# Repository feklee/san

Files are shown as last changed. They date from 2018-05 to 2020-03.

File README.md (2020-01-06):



Introduction
============

*Knowing yourself is the beginning of all wisdom* ― Aristotle

SAN (Self Aware Network) is an experiment about the [future of
architecture][1]. The network understands its own topology, a first
step towards being able to dynamically adapt to its environment.

SAN is an intermediate step: [Manifesto][6]

Getting started
===============

 1. Build nodes, edges, and the root node.

 2. Program the root node and the nodes.

 3. If using the USB root node, connect that to your computer, then run the web
    app.
    
    If using the WiFi root node, simply connect to it with a web browser.
    
 4. Build a structure.

There may be [apps][5] built on top of the system.

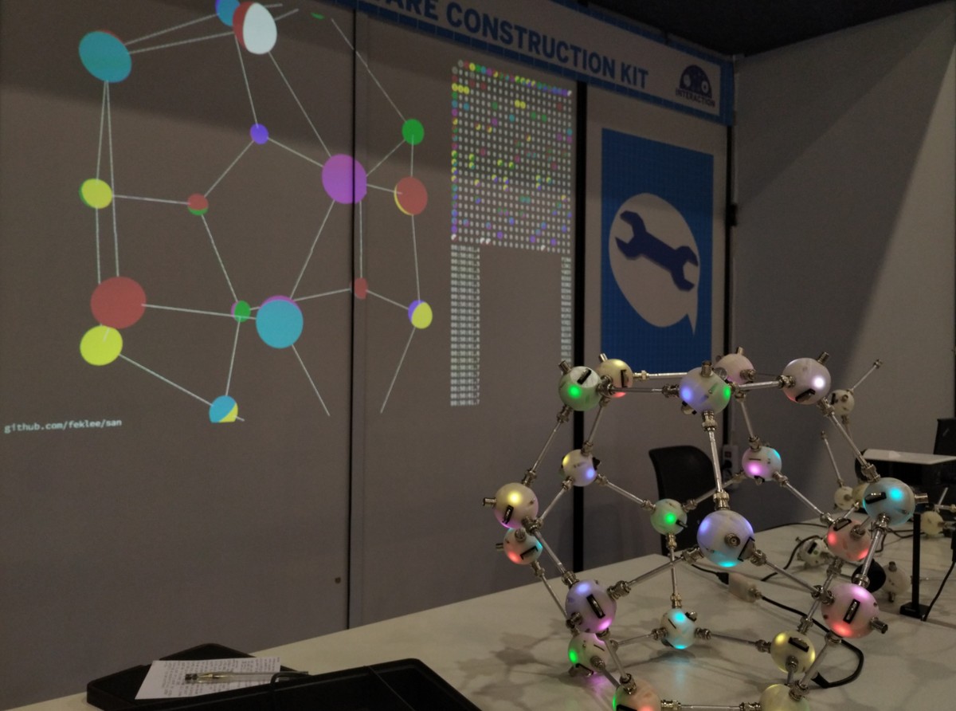
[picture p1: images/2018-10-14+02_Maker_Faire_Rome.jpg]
Photo of setup at Maker Faire Rome 2018


Acknowledgments
===============

  * [Cong Nguyen][2] for helping with PCB design

  * [David Mickisch][3] for mathematical advise and for writing the
    experimental [San-Optimizer][4]
    
  * Herbert Poetzl for advice on electronics and for the suggestion to
    use optical communication between nodes
  
  * Loay Yari for helping with PCB design and manufacturing
    
  * [Pietro Mincuzzi][7] for the o-ring trick
  
  * Kliment for advice on electronics, optics, and the ESP32

License
=======

Except where noted otherwise, files are licensed under the WTFPL.

Copyright © 2018–2020 [Felix E. Klee](felix.klee@inka.de)

This work is free. You can redistribute it and/or modify it under the terms of
the Do What The Fuck You Want To Public License, Version 2, as published by Sam
Hocevar. See the COPYING file for more details.

[1]: https://feklee.github.io/san/notes/128a47a0-23ea-11e9-a8da-000c296198cf/
[2]: https://github.com/rampadc
[3]: https://github.com/davidblitz
[4]: https://github.com/davidblitz/san-optimizer
[5]: https://feklee.github.io/san/notes/f8d89da9-c285-4b5a-921b-7af3444b9229/
[6]: https://feklee.github.io/san/notes/0411b82f-268f-46b2-9563-efaf14a68a41/
[7]: https://pietro.mincuzzi.asia

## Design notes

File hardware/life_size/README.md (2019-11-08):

Introduction
============

The life size version of SAN is made of coconuts (nodes) and bamboo canes
(edges), connected with quick-connectors. Information gets transmitted by IR
light.

Reading
=======

  * [SAN: Coco Nodes & Bamboo Edges][1]

[1]: https://feklee.github.io/san/notes/117bf77c-e5ba-11e9-9ada-000c296198cf/

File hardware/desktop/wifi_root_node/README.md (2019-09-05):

Introduction
============

The WiFi root node runs a web app which provides a bridge from the network (SAN)
to mobile devices such as phones.

Material
========

Components
----------

  * 3000 mAh battery: 80×50×6 mm

  * Adafruit 757: 4-channel I2C-safe bi-directional logic level converter -
    BSS138

  * Adafruit 2465: PowerBoost 1000 charger – rechargeable 5V LiPo USB boost @
    1A - 1000C

  * Adafruit 4090: USB C breakout board – downstream connection

  * Raspberry Pi Zero W

  * microSD card

  * BNC connector: Amphenol RF 31-221-RFX

  * SPDT switch: Sourcingmap A12013100UX0116

  * 4 × Screws: DIN 912, M2×5 mm

  * 4 × Nuts: DIN 934, M2

  * PLA for 3D printing

  * cables / wires

Additionally, helpful
---------------------

  * P400 grid sandpaper

  * Blu Tack (to help with fixing cables and components when soldering)

Case
====

Print the top and bottom of the case, place the components inside, and solder
them.

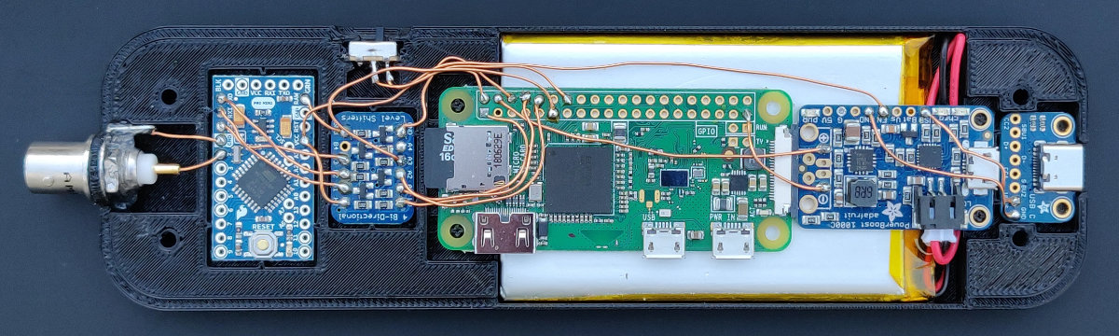
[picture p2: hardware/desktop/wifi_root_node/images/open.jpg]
Open case


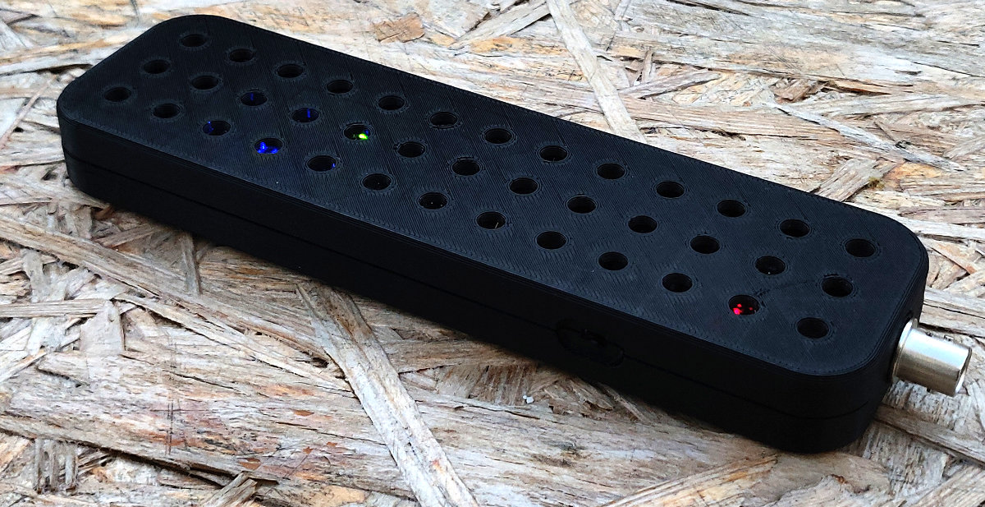
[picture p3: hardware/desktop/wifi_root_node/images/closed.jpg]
Closed case


Software setup
==============

  * Install Linux on the Pi Zero, tested with Raspbian Buster Lite.

  * Install the web app.

  * Set up the Pi as a [WiFi access point][1].

  * Create a systemd service unit that runs the web app. Enable and start the
    service:

        $ sudo ln -s "$PWD/san.service" /etc/systemd/system/
        $ sudo systemctl start san.service
        $ sudo systemctl enable san.service

    See also [systemd services][2] on the Raspberry Pi.

  * To redirect all DNS queries, setup “dnsmasquerade”:

        # ln -s "$PWD/redirectallhosts" /etc/dnsmasq.d/

    See also the blog post [DNS: Configure DNS to return the same IP Address for
    all hostnames][3].

  * To redirect all IPs to SAN, “iptables” is used.

        $ sudo vim /etc/sysctl.conf
        $ grep net.ipv4.ip_forward /etc/sysctl.conf
        net.ipv4.ip_forward=1
        $ sudo apt install iptables-persistent
        $ sudo iptables -t nat -A PREROUTING -p tcp --dport 80 -j DNAT \
          --to-destination 192.168.4.1:8080
        $ sudo iptables -t nat -A POSTROUTING -j MASQUERADE
        $ sudo iptables-save | sudo tee /etc/iptables/rules.v4

    See also:
    
      + Raspberry Pi forum post [Re: Captive Portal - Redirect all IP to Single
        IP][4].

      + `/etc/sysctl.conf`: To enable packet forwarding.

  * Install the official Arduino software with CLI support:

        $ wget https://downloads.arduino.cc/arduino-1.8.9-linuxarm.tar.xz
        $ tar xf arduino-1.8.9-linuxarm.tar.xz
        $ cd arduino-1.8.9-linuxarm
        $ sudo ./install.sh

  * Install: git@github.com:deanmao/avrdude-rpi.git

        $ export BIN=$HOME/arduino-1.8.9/hardware/tools/avr/bin
        $ cp avrdude-rpi/autoreset $BIN
        $ cp avrdude-rpi/avrdude-autoreset $BIN
        $ mv $BIN/avrdude $BIN/avrdude-original
        $ ln -s $BIN/avrdude-autoreset $BIN/avrdude

    Adapt paths:

        $ vim $BIN/avrdude-autoreset
        $ grep strace $BIN/avrdude-autoreset
        strace -o "|/home/pi/arduino-1.8.9/hardware/tools/avr/bin/autoreset" -eioctl /home/pi/arduino-1.8.9/hardware/tools/avr/bin/avrdude-original $@

  * Configure serial connection between Pi and Arduino according to the blog
    post [Raspberry Pi and Arduino connected over serial GPIO][5].

    Changes:

      + To stop and disable getty. See the documentation on [the Raspberry Pi
        UARTs][6].

      + Maybe also do:

            $ sudo systemctl stop serial-getty@ttyAMA0.service
            $ sudo systemctl disable serial-getty@ttyAMA0.service
            $ sudo systemctl disable getty@

      + Test:

            $ ~/arduino-1.8.9/arduino \
              --board arduino:avr:pro:cpu=16MHzatmega328 \
              --port /dev/serial0 \
              --upload ~/arduino-1.8.9/examples/01.Basics/Blink/Blink.ino

  * Install required libraries:

        $ ~/arduino-1.8.9/arduino --install-library "MultiTrans"
        $ ~/arduino-1.8.9/arduino --install-library "Adafruit NeoPixel"

  * Upload the root node firmware to the Arduino. The root node is programmed
    just like the other nodes. The root node needs to have as ID: `^`

    When uploading, first make sure that no other software, such as SAN, is
    accessing the serial port!

        $ ~/arduino-1.8.9/arduino \
          --board arduino:avr:pro:cpu=16MHzatmega328 \
          --port /dev/serial0 --upload ~/san/nodes/Firmware/Firmware.ino

  * Optionally, set up an overlay file system.
  
    It may happen that power is removed while the Raspberry Pi is writing to its
    microSD card. In this case, the card may become corrupted. To alleviate the
    problem, the root file system may be mounted read-only with an overlay file
    system on top, following the guide [Raspberry Pi Overlay Root
    Filesystem][7].

    The home directory may be on a separate partition which is writeable. During
    normal operation of SAN, there should be no writes to the home directory.

To view serial output
=====================

First make sure that no other software, such as SAN, is accessing the serial
port!

    $ screen /dev/serial0 9600 # or any other appropriate baud rate

To give the Pi access to the Internet via a Linux system
========================================================

On the connecting computer:

 1. Set “$INET” to the network interface connected to the Internet.

 2. Set “$PI” to the interface to be connected to the Raspberry Pi.

 3. Connect and set up IP forwarding:

        # iw dev $PI connect SAN
        # sysctl net.ipv4.ip_forward=1
        # iptables -t nat -A POSTROUTING -o $INET -j MASQUERADE
        # iptables -A FORWARD -m conntrack --ctstate RELATED,ESTABLISHED -j ACCEPT
        # iptables -A FORWARD -i $PI -o $INET -j ACCEPT

On the Pi:

 1. Set “$GW” to the IP of the interface “$PI” on the computer.

 2. Set up routing via the default gateway:

        $ sudo route add default gw $GW

[1]: https://www.raspberrypi.org/documentation/configuration/wireless/access-point.md
[2]: https://www.raspberrypi.org/documentation/linux/usage/systemd.md
[3]: https://michlstechblog.info/blog/dns-configure-dns-to-return-the-same-ip-address-for-all-hostnames/
[4]: https://www.raspberrypi.org/forums/viewtopic.php?f=66&t=90155&p=764850#p764850
[5]: https://oscarliang.com/raspberry-pi-and-arduino-connected-serial-gpio/
[6]: https://www.raspberrypi.org/documentation/configuration/uart.md
[7]: https://yagrebu.net/unix/rpi-overlay.md

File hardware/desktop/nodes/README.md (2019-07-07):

Introduction
============

Nodes are 3D printed, composed of two hemispheres that are screwed.

Parametric design (Fusion 360): http://a360.co/2FMH0TC

Inside of each node there is a tiny microcontroller, an Arduino Pro Mini.

In the future, it may be interesting to put cameras into nodes for
[AI based visual self awareness][1].

Geometry
========

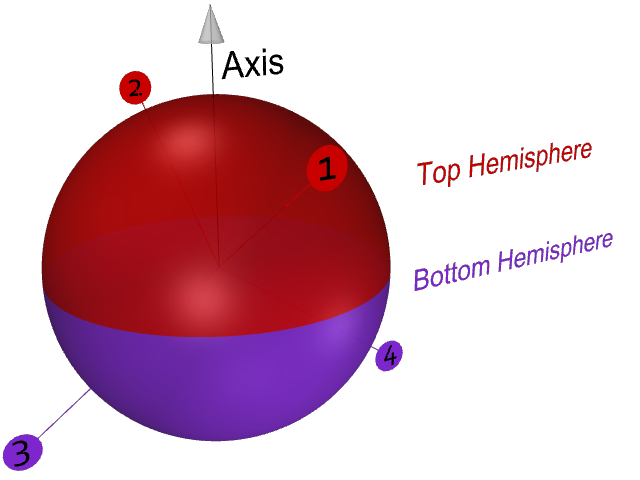
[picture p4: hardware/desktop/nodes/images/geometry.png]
Annotated illustration of the node geometry


Parts
=====

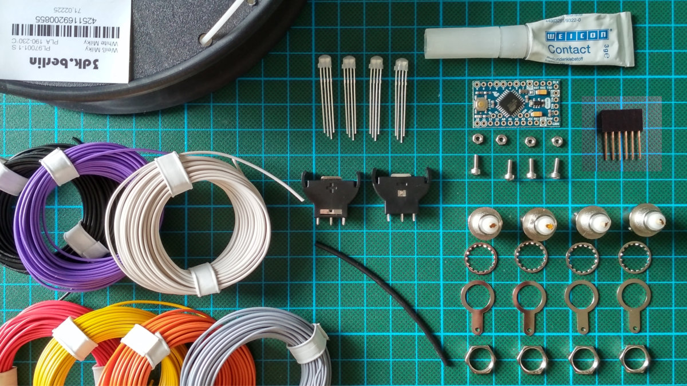
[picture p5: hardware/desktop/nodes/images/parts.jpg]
Parts


  * Arduino Pro Mini

  * Flexible cables in different colors. Below we use: red, black, yellow,
    white, purple, orange, gray

    Size tested: 0.14 m² = 26 AWG (thinner cables could be easier to work with)

  * Heat shrink to accommodate two cables.

  * 4 × BNC connectors: Amphenol RF 31-221-RFX

  * 4 × LED: WS2811 F5 (5 mm short head)

  * 2 × vertical battery holder: KZH 20PCB-V

  * Glue for PLA plus PVC

  * Milky transparent plastics for 3D printing.

  * 4 × Screws: DIN 912, M2×5 mm

  * 4 × Nuts: DIN 934, M2

  * 6 pin header, stackable, i.e. with long pins

Additionally, helpful are:

  * P400 grid sandpaper
  
  * Blu Tack

Assembly
========

 1. Hemispheres:

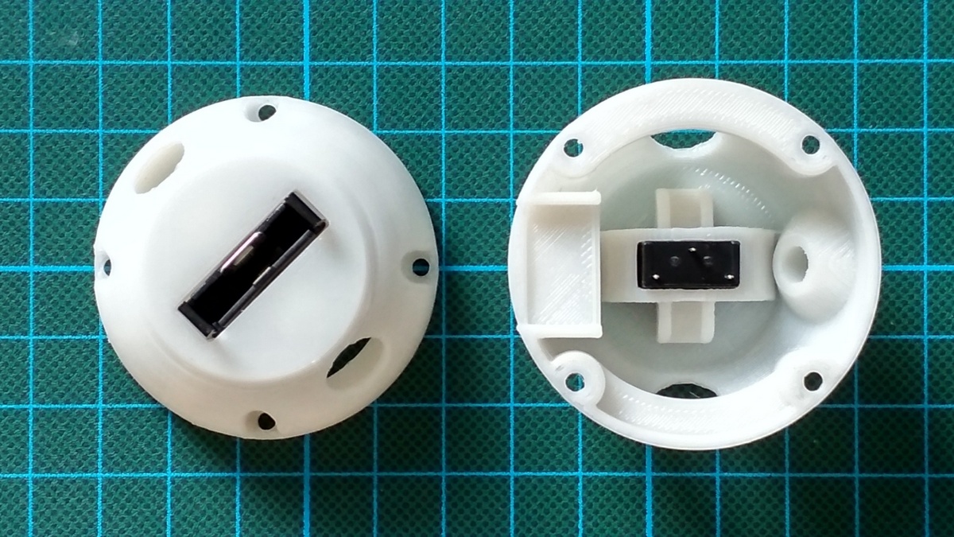
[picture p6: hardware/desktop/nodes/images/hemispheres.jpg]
Hemispheres
    

     1. 3D print two copies:

          - See the provided STL file: `hemisphere.stl`

          - Orient upside down.

          - Print without raft and support.

          - Print with high amount of infill to get smooth light from the LEDs.
          
        Optionally, you may print the hemisphere without receptacle
        for use as the bottom part (`hemisphere_optional_bottom.stl`).
        Functionally this is not necessary, however.

     2. Cut excess material. Make sure that the LEDs fit into the
        receptacles.

     3. Using P400 grid paper, wet sand the top of the print so that
        the hemispheres are flush when joined.

     4. Glue in battery holders using gap-filling glue, as pictured:

          - hemisphere upside down

          - receptacle for 6 pin header on the left

          - ⊕ in back

 2. Cables:

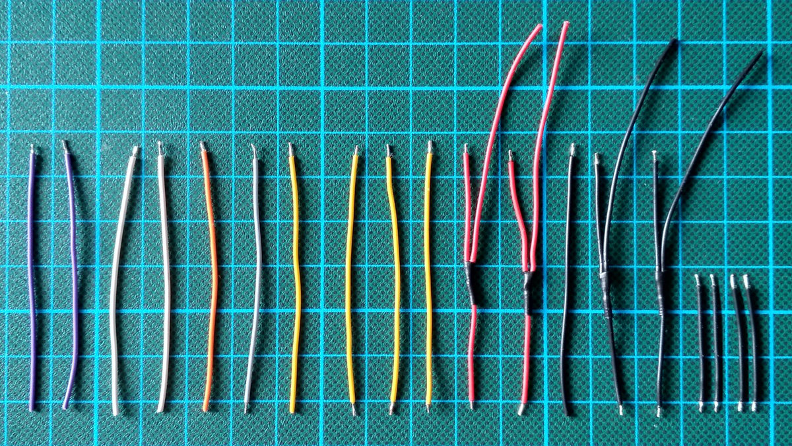
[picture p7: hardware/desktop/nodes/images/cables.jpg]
Cables
    

     1. Cut:

          - black: 5 × 60 mm, 4 × 30 mm

          - red: 4 × 60 mm

          - yellow: 4 × 60 mm

          - purple, white: 2 × 60 mm (of each color)

          - gray, orange: 1 × 60 mm (of each color)

     2. Strip (2 mm) one end of:

          - yellow, orange: 1 × 60 mm (of each color)

          - red, purple, white: 2 × 60 mm (of each color)

          - black: 3 × 60 mm

     3. Strip both ends and the middle of:

          - red, black: 2 × 60 mm (of each color)

     4. Strip both ends of all remaining cables.

     5. Tin wires.

     6. Solder y-cables using the cables that are stripped in the middle plus
        the 60 mm cables that are stripped on just one end.

     7. Put 10 mm heat shrink tube on connections of y-cables.

 3. BNC connectors:

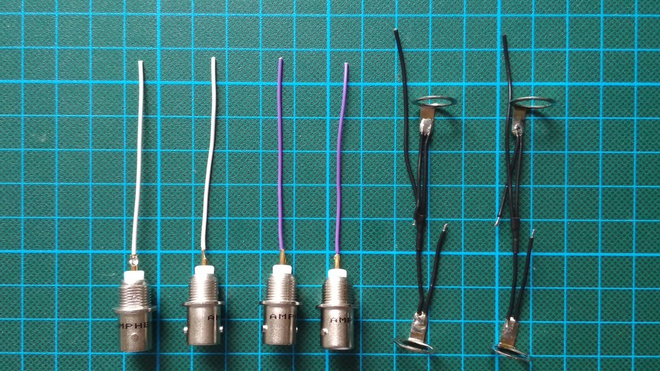
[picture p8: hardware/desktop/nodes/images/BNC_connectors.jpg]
BNC connectors
    

     1. Bend solder tags by 90°.

     2. Verify that bent solder tags fit in hemisphere.

     3. Tin solder tags.

     4. Solder one black y-cable and one short black cable onto each
        solder tag. Put the short cable on the left side, with the
        solder tag pointing towards you.

     5. Solder cables to the contact pins: white, purple

 4. LEDs:

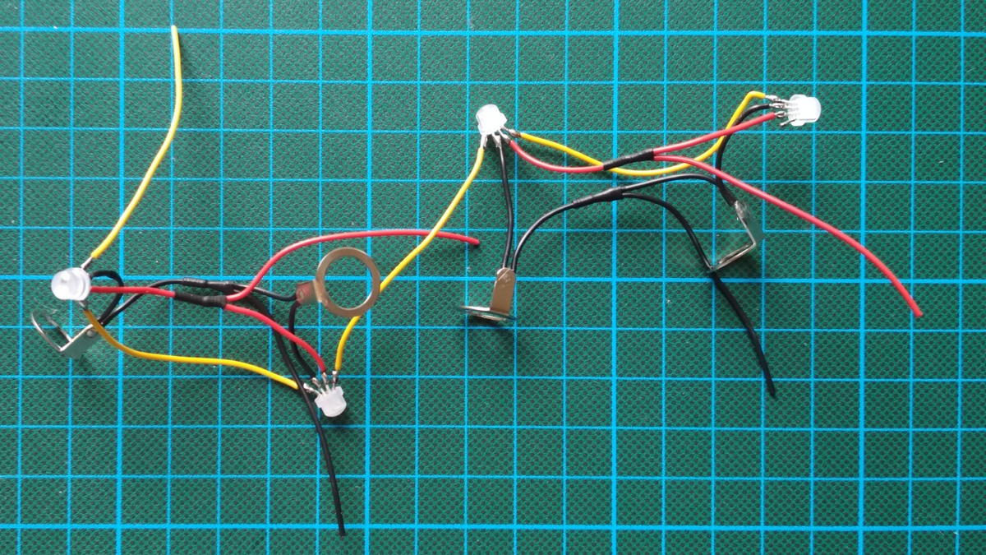
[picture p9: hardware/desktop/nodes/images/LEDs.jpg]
LEDs
    

     1. Test them using the provided Arduino sketch.

     2. Shorten pins of LEDs to 5 mm.

     3. Bend pins to spread them.

     4. Tin pins.

     5. Solder to first LED, from left to right:

          - (round side)

          - DIN: yellow cable, tinned on one end

          - VDD: black cable, short, attached to a BNC solder tag

          - VSS: red y-cable, one of the two tinned ends

          - DOUT: yellow cable

          - (flat side)

     6. Solder to second LED:

          - DIN: yellow cable, connected to DOUT on first LED

          - VDD: black cable, short, connected to the first LED

          - VSS: red y-cable, connected to first LED

          - DOUT: yellow cable

      7. Solder to third LED:

          - DIN: yellow cable, connected to second LED

          - VDD: black cable, short, attached to BNC connector

          - VSS: red y-cable

          - DOUT: yellow cable

      8. Solder to fourth LED:

          - DIN: yellow cable, connected to third LED

          - VDD: black cable, short, attached to BNC connector

          - VSS: red y-cable

 5. Battery holders:

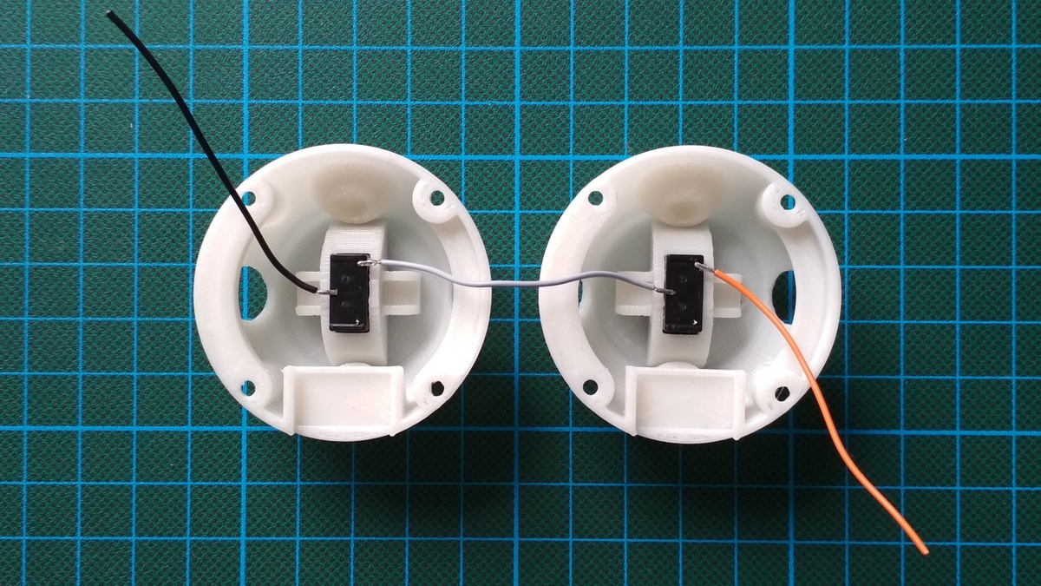
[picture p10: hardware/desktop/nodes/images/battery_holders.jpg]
Battery holders
    

     1. Cut off one of each ⊕ connector pins completely.

     2. Tin pins.

     3. Solder to battery holder in the bottom hemisphere:

          - ⊖: black cable

          - ⊕: gray cable

     4. Solder to second battery in the top hemisphere:

          - ⊖: gray cable, connected to other battery holder

          - ⊕: orange cable

     4. Bend pins flat.

 6. Arduino Pro Mini board:

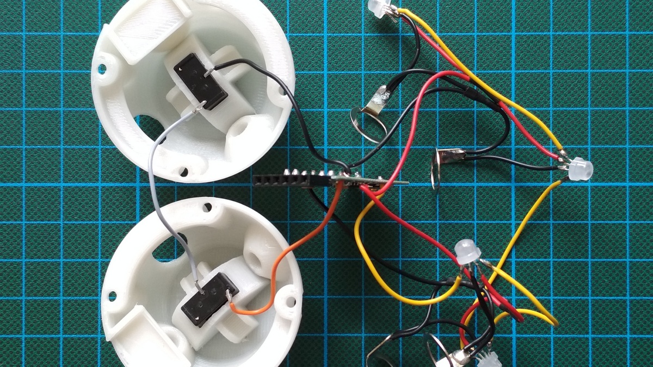
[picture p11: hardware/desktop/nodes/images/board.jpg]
Board
    

     1. Desolder the power LED from the Arduino Pro Mini (works good
        with a soldering iron and a little tin on its tip, as shown in
        the video “Desoldering led and voltage regulator on Arduino
        Pro Mini”: <https://www.youtube.com/watch?v=7qujkC72dYs>)
        
        Desoldering the power LED reduces power consumption, and it
        avoids an glow inside the sphere.
        
     2. Remove the reset button. This can be done simply by cutting
        its legs with a wire cutter.
        
        Removing the reset button saves a little space, and it
        prevents it from accidentally being pressed.

     3. Bend the six pin connector so that board with the connector fits into a
        hemisphere. Suggestion: Test by bending one pin first.

     4. Solder six piece connector to board.

     5. Solder cables into the upper side of the board, after
        stripping ends (fixing cables with Blu Tack makes things easier):

          - Pin 4: yellow cable

          - GND between RST and 2: black cable connected to the two
            LEDs with the yellow cable soldered to A0

          - VCC: both red cables

          - RAW: orange cable

     6. Solder cables into the bottom side of the board, after stripping ends:

          - GND between RST and RAW: remaining black cables

 7. BNC connectors in sphere:

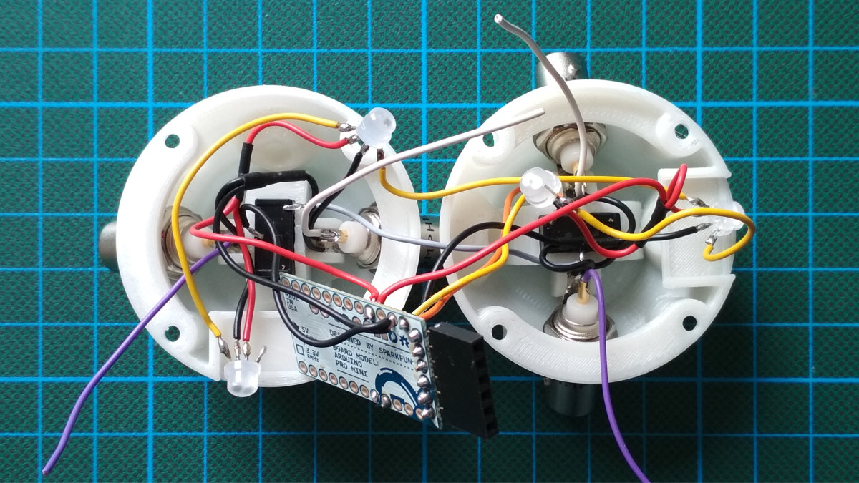
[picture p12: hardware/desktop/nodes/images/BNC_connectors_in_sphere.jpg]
BNC connectors in sphere
    

     1. Thread contact pin cables through holes in hemispheres:

          - First cable, white: same hemisphere and side as the orange
            cable (top hemisphere)

          - Second cable, purple: same hemisphere as the above white
            cable (top hemisphere)

          - Third cable, white: other hemisphere, next to the gray cable (bottom
            hemisphere)

          - Fourth cable, purple: remaining position (bottom hemisphere)

     2. Screw onto each connector from the inside, but not super tight yet:

         1. lock washer

         2. solder tag: The solder tag for the first LED (see earlier step) goes
            with the first cable (see above), the solder tag for the second LED
            with the second cable, etc.

         3. hex nut

        It may be easier to first position the solder tag, then push the lock
        washer underneath, position the hex nut on top, and finally screw the
        connector through that.

 8. Contact pin cables on board:

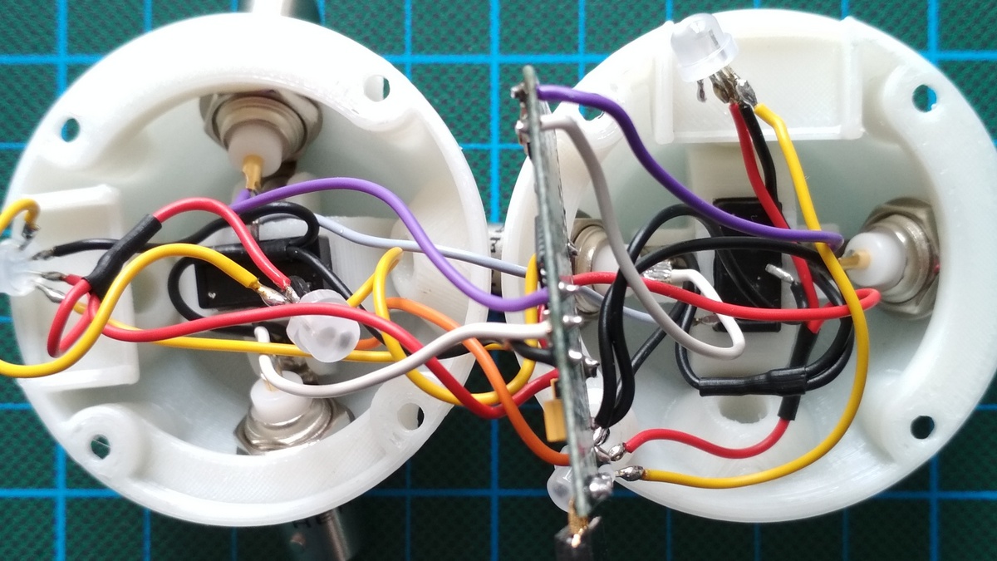
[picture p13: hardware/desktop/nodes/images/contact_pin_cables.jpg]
Contact pin cables
    

      1. First and second cable (see earlier step) go into the upper side of the
         board:

          - Pin 2: white

          - Pin 3: purple

      2. Remaining cables go into the bottom side of the board:

          - Pin 8: white

          - Pin 9: purple

 9. LED positions:

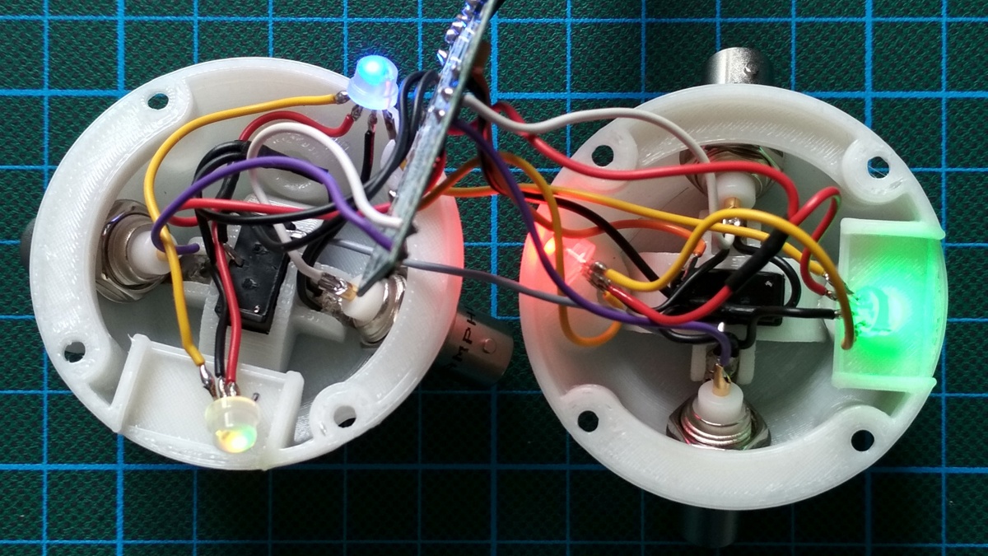
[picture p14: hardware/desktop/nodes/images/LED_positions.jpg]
LED positions
    

      - Move each LED near the hole on the side of the solder tag where the
        black cable is soldered to.

      - Test the position of the LEDs using the provided sketch: red, green,
        blue, yellow

10. Glued parts:

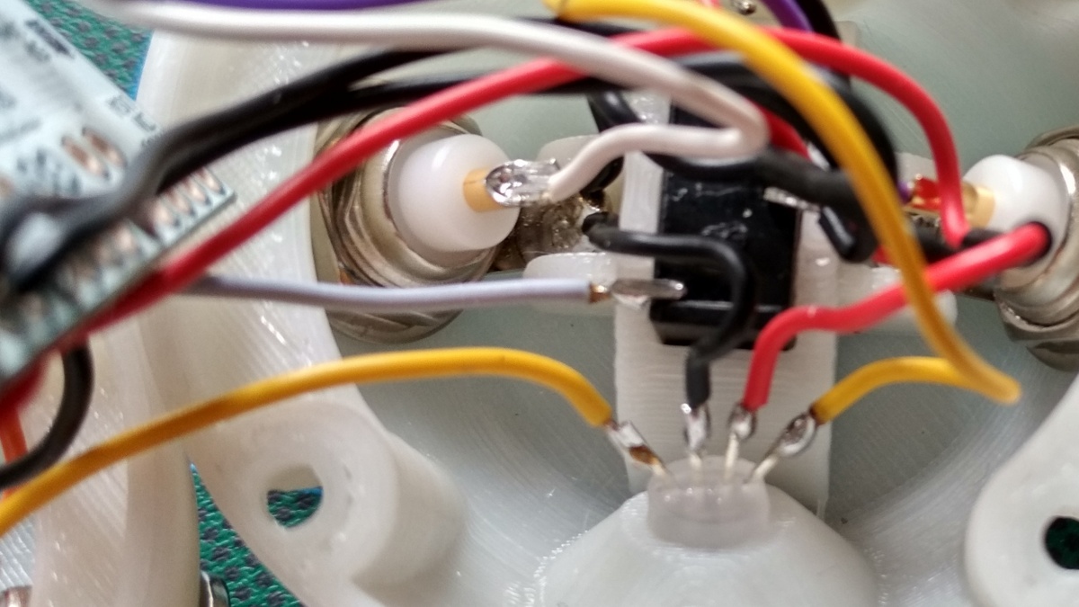
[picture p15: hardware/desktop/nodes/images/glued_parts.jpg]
Glued parts
    

      - Tighten the BNC connectors with the help of pliers and a female BNC
        connector.

      - Glue the LEDs into the respective holes.

      - Use a drop of glue to secure each BNC connector against rotation.

11. Sphere:

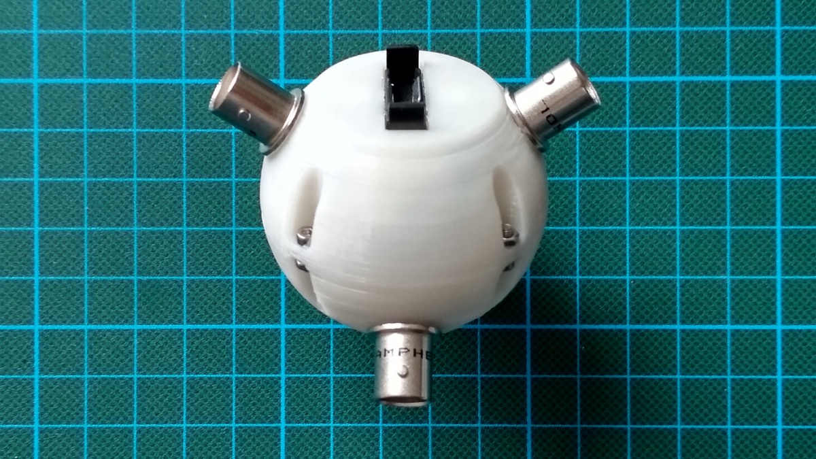
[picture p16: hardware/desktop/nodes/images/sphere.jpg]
Sphere
    

      - Positioning the board according to the direction that the cables go in.

      - The six pin header is held in place by the wide flange in one of the
        quadrants.

      - Use the M2 screws and nuts to hold the assembly together.

Programming
===========

 1. If accelerometer is connected in the node, then calibrate it:

      - Build and upload `AngleTableBuilder` to node.

      - Open the Arduino serial console.

      - Turn the node over its *perfectly horizontal* and over its *upside down*
        positions. Do so carefully, i.e. without adding measurable acceleration.

      - Create the angle table, and store it in: `Firmware/angleTables` with the
        ID of the node.

 2. Install the firmware:

      - Set the ID in `Firmward/id.h`. (described in `Firmware/Firmware.ino`)

      - Build and upload `Firmware`.

Reading
=======

  * [SAN: Structural Engineering][1]

[1]: https://feklee.github.io/san/notes/2efde1ae-0222-484c-82e9-d3373084aab3/

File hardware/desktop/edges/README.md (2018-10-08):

Introduction
============

Edges are basically stiff RG58 cables. The metal shell is connected to
ground.

Parts
=====

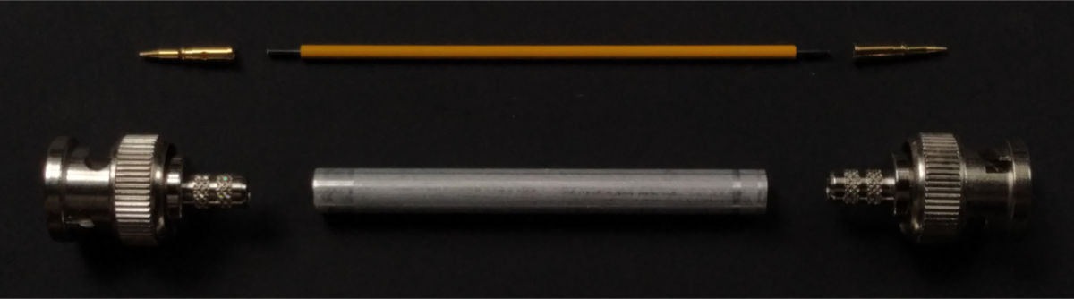
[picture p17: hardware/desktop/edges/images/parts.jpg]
Parts


  * 2 × RG58 BNC crimp coaxial connector with contact pins: Amphenol RF 112116

  * Aluminum pipe, 6 mm outer diameter, 0.5 mm wall thickness, 60 mm length

  * ABS coated wire, 1.0 mm wire diameter, 1.6 mm outer diameter:
    [Modulor Item #4500359-002-ST][1]

    Isolation cut to a length of 66 mm

Consider adding a resistor as a protection against shorting when nodes are
connected in loops: [Half Duplex: How to prevent shorting?][2] (Electrical
Engineering StackExchange)

Assembly
========

 1. Scrape off oxide layer from stripped wires.

 2. Crimp contact pins.

 3. Assemble. The contact pins require some force to click into the connectors.

 4. Crimp pipe to fix connectors.

    Finished edge

[1]: https://www.modulor.de/en/abs-round-tube-opaque-coloured-oe-1-6-l-760-mm-wire-yellow.html
[2]: https://electronics.stackexchange.com/q/368116/21817

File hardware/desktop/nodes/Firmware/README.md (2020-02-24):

Flashing from Linux command line
================================

Example on Linux (replace device name and node ID as needed):

    $ ./upload.sh /dev/ttyUSB0 A

To view serial output (to quite, press <kbd>Ctrl</kbd>-<kbd>a</kbd> followed by
<kbd>k</kbd>):

    $ screen /dev/ttyUSB0 115200

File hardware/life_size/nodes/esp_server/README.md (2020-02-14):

Introduction
============

The ESP-EYE sends information about neighbors of the current node to the
network’s brain.

Development with USB connection
===============================

  * Flashing:
  
      - Make sure that the correct camera pinout is selected:
  
            $ make menuconfig

      - Build and upload: (high baud rate)

            $ python2 $(which idf.py) -p /dev/ttyUSB0 flash --baud 2000000
            
      - Re-plug the USB connection, or else monitoring won’t work.

  * Monitoring:
  
      - If the Arduino is connected, keep the reset button pressed.

        *Background:* Unless floating, the CLK pin needs to be pulled high, or
        else the ESP-EYE won’t boot.
      
      - Start the monitor:

            $ python2 $(which idf.py) -p /dev/ttyUSB0 monitor
            
      - Wait until the ESP-EYE has booted.
      
      - Release the Arduino’s reset button.

  * Troubleshooting if the video stream doesn’t load: Check with the example
    camera web server included with ESP-WHO. Maybe the camera is not properly
    connected.

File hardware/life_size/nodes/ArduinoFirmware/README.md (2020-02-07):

Introduction
============

The Arduino Pro Mini communicates optically with other nodes, and it
communicates via SPI with the ESP-EYE.

Flashing from Linux command line
================================

Example on Linux (replace device name, MHz speed, and node ID as needed):

    $ ./upload.sh /dev/ttyUSB0 8 A

To view serial output (to quite, press <kbd>Ctrl</kbd>-<kbd>a</kbd> followed by
<kbd>k</kbd>):

    $ screen /dev/ttyUSB0 115200

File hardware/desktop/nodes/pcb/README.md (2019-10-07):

Introduction
============

The node PCB simplifies assembly compared to assembly from a multitude of
individual components connected to an Arduino Pro Mini board.

Most components can be found in Seeed Studio’s [OPL][1], the Open Parts Library.

Additional components
=====================

For programming:

  * Tag-Connect cable without legs (NL = no legs): TC2030-IDC-NL
  
  * Tag-Connect retaining clip: ‎[TC2030-CLIP-ND‎][3]
  
  * Mini-USB cable with loose ends
  
  * FTDI 5V TTL-232R USB – TTL level serial converter: [TTL-232R-5V-WE][7]
  
  * Heat-shrink tubing: for assembling the FTDI-to-Mini-USB cable

For each node (not part of PCBA):
  
  * FFC, 0.5mm, 6 pos: [Molex 0151660051][8]
  
  * 4 × programmable RGB LED: WS2812D-F5
  
  * 2 × CR2032 SMD battery holder: [BK-912][4]
  
  * 4 × BNC connector: [31-221-RFX][5]
  
  * 4 × PicoBlade cable: [Alibaba][6]
  
  * 2 × CR2032
  
  * ADXL337 (optional, hard to solder)
  
  * 4 × screw: DIN 912, M2×5 mm
  
  * 4 × nut: DIN 934, M2

Burning the boot loader to the PCB
==================================

To burn the bootloader onto the 328P:

  * Mount the shield onto an Arduino Uno.
  
  * Use the Tag-Connect cable to connect the shield and the PCB.
  
  * Use the `ArduinoISP` sketch (in examples distributed with the Arduino 1.8.8
    IDE) to burn the boot loader to the PCB.

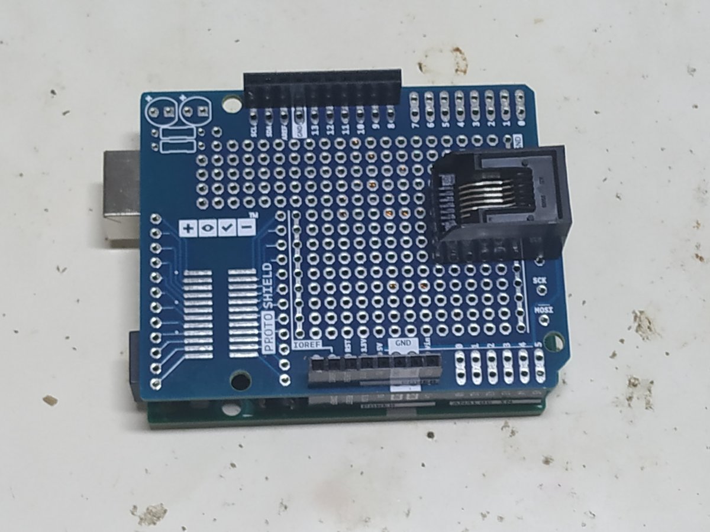
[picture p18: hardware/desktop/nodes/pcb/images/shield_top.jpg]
Burner shield top


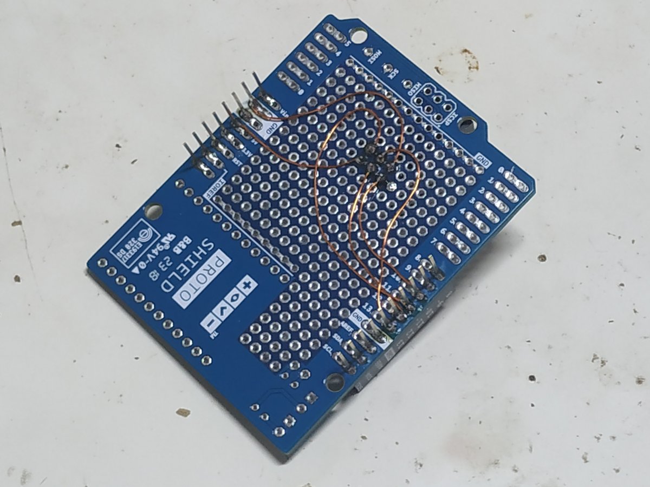
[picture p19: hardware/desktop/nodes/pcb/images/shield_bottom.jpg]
Burner shield bottom


Reading
=======

[SAN: PCB Design][2]

[1]: https://www.seeedstudio.com/opl.html
[2]: https://feklee.github.io/san/notes/db95a440-7520-4fa2-a001-c076d31a4e77/
[3]: https://www.digikey.de/short/pjm9zh
[4]: https://www.digikey.de/short/pjm9pw
[5]: https://www.digikey.de/short/pjm9pm
[6]: https://www.alibaba.com/product-detail/molex-picoblade-51021-1-25mm-pitch_60690837931.html
[7]: https://www.digikey.de/short/pjmbpr
[8]: https://www.digikey.de/short/pjmbw3

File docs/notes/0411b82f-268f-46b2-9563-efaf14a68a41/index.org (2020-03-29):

#+HTML_HEAD: <style>body{max-width:42em}img{max-width:100%}.figure-number{display:none}</style>

#+TITLE: SAN: Manifesto

* Intention

The intention is to democratize architecture the way maker spaces have
democratized industrial design.  And of course we’re not creating static
buildings of the last millennium.  We’re inviting the buildings to partake in
their construction.

* What to strive for in a project

1. /Accessibility:/ Digital fabrication lowers the barrier of entrance.  It
   should not be required to have architectural training or to possess
   particular manual skills.  Everybody is invited.

2. /Inhabitability:/ Some of the best projects are those that are for personal
   use.  In an architectural maker space, it should be possible to live in the
   structures built, even if only temporarily.

3. /Reconfigurability:/ In a typical maker space, a lot of prototypes go to
   waste.  This is not feasible at architectural scale.  For example, instead of
   experimenting with 3D printing, it may be more interesting to work on a robot
   that can assemble and reconfigure constructions out of simple building
   blocks.  Architecture probably should be less rigid anyhow, able to adapt to
   changing needs.

4. /Fast production:/ Ideally, constructions can be quickly assembled, for fast
   iteration and for getting results in an afternoon.

* SAN as an intermediate step

The [[https://github.com/feklee/san][Self Aware Network]] (SAN) is an intermediate step.  Individuals join a
collaborative construction process.  The network gives visual and auditory
feedback concerning how it perceives its construction and its integration with
the environment.  It is not a habitable structure however.

#+CAPTION: Concept for [[https://feklee.github.io/san/notes/37a9c365-c0a9-45d4-bf89-23a359c176fa/][UABB]]
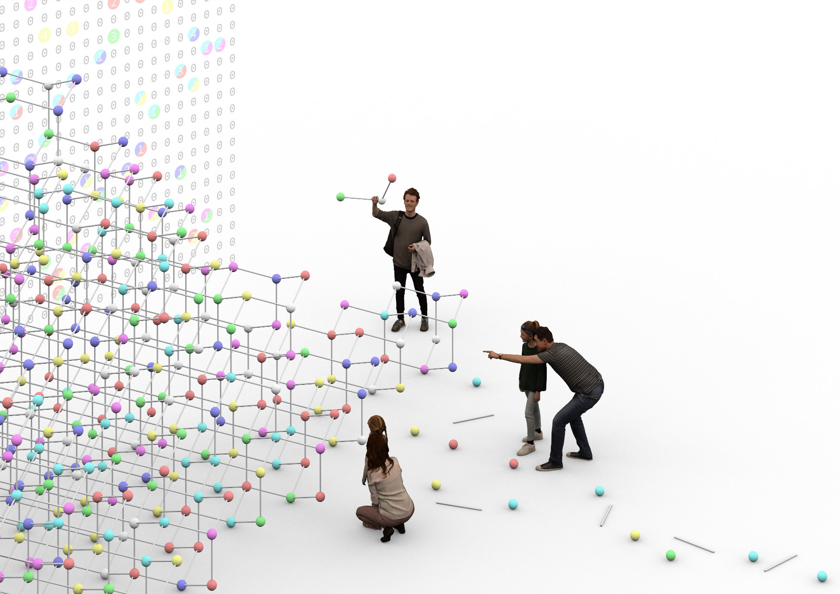
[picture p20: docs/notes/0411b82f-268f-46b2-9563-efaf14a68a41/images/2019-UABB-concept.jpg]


* Beyond SAN

- /Organic buildings:/ Just as [[https://en.wikipedia.org/wiki/Full_Grown][chairs]] out of trees or objects out of [[https://en.wikipedia.org/wiki/Ecovative_Design][mycelium]] –
  houses could be grown.  Such buildings are literally partaking in their
  construction.  A start would be small scale models grown over the course of a
  few weeks or months.  Experiment with using electronics, light, and AI to
  influence growth without human intervention.

- /Sustainability and robotics:/ Robots may be able to construct individualized
  buildings from scrap found on the ground in way more sophisticated ways than
  humans.  Furthermore, buildings can be reconfigured continuously, preventing
  waste of material and offering endless possibility for play and
  experimentation.

- /Portable construction machine:/ Let’s invent a portable machine that you can
  take with you, and that aids with building a shelter for a night.

- /Open source skyscraper:/ Exercise to build high to make good use of a small
  footprint.

- /Jungle sound:/ Embed electronic sensors into the jungle that measure features
  of plants as they grow.  Make the generation of nice sound an objective.
  Learn about the properties of plants and how they move and grow.

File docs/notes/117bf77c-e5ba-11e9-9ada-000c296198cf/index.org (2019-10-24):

#+HTML_HEAD: <style>body{max-width:42em}img{max-width:100%}.figure-number{display:none}</style>

#+TITLE: SAN: Coco Nodes & Bamboo Edges

* Introduction

The /Self Aware Network/ (SAN) is a kit for assembling architectural structures
that are aware of themselves.  A structure is comprised of a network.  Nodes
communicate and send information to the brain, a computer which is able to
understand what has been built.  Structures communicate with the environment
visually and auditory.

#+BEGIN_EXPORT html
<iframe width="560" height="315" src="https://www.youtube.com/embed/u5LrP_wYdv0" frameborder="0" allow="accelerometer; autoplay; encrypted-media; gyroscope; picture-in-picture" allowfullscreen></iframe>
#+END_EXPORT

* Objectives of this document

- Find a way to scale up SAN, using coconuts and bamboo canes as elements

- Decide on components.

- Design PCB for controller.

- Design PCB for IR transceiver.

- Create a manufacturing ready board layouts.

- Optimize price and manufacturing time.

* SAN desktop system

The SAN desktop system is fully functional, asides from a bunch of bugs.  Nodes
are 3D printed spheres with a diameter of 50 mm.  Edges have a length of 100 mm.
Nodes and edges are connected using BNC connectors.  Signals are transmitted via
wires to the network’s brain using a two layer protocol based on [[https://github.com/feklee/MultiTrans/][MultiTrans]].

#+CAPTION: Desktop system at Maker Faire Berlin 2019, photo © Tobi Giessen
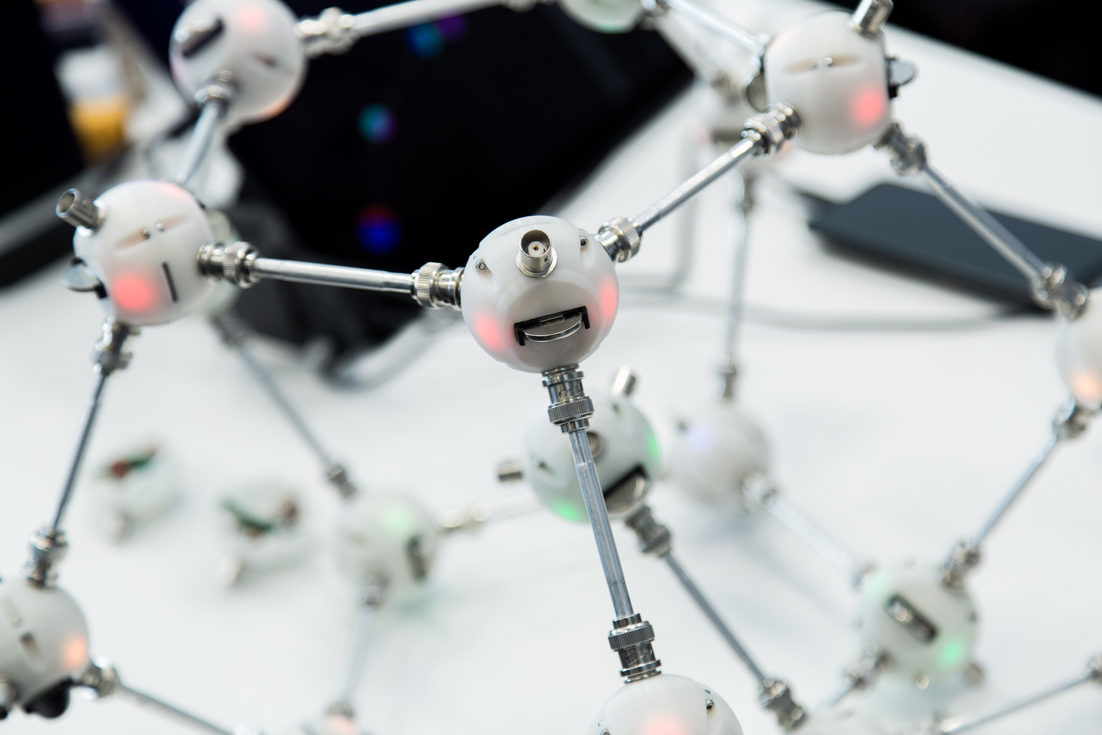
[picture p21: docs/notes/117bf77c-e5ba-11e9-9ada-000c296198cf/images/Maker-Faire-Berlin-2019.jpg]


* SAN life-size system

The SAN life-size system is under development.  It is not functional.  Only part
of it has been prototyped.  Nodes are coconuts of about 150 mm diameter, and
edges are bamboo canes of 500 mm in length.  Nodes identify themselves to their
neighbors using IR traveling through the bamboo canes.  Nodes send information
to the brain wirelessly.  No complex protocol is required.

#+CAPTION: Porposal for the deTour 2019 art festival Hong Kong
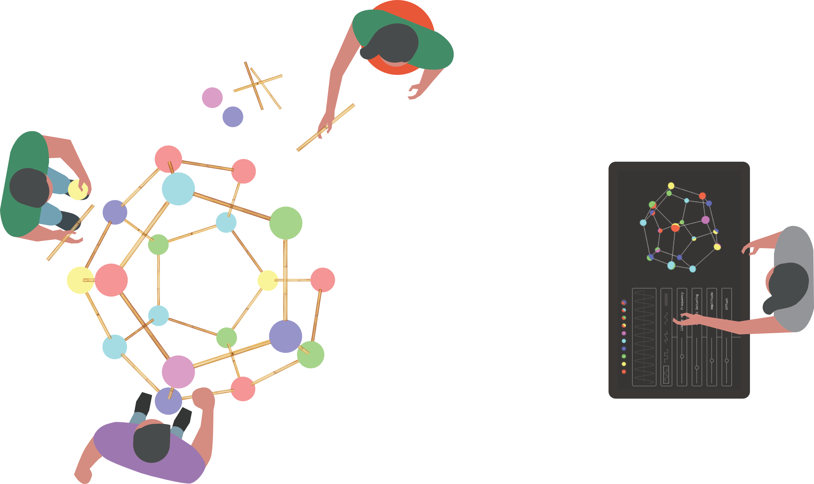
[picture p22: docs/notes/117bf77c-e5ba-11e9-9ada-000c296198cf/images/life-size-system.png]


* Brain

The brain is the central computer that visualizes the network and that allows
controlling how nodes in the network generate and modulate sound.

#+CAPTION: Control panel of brain
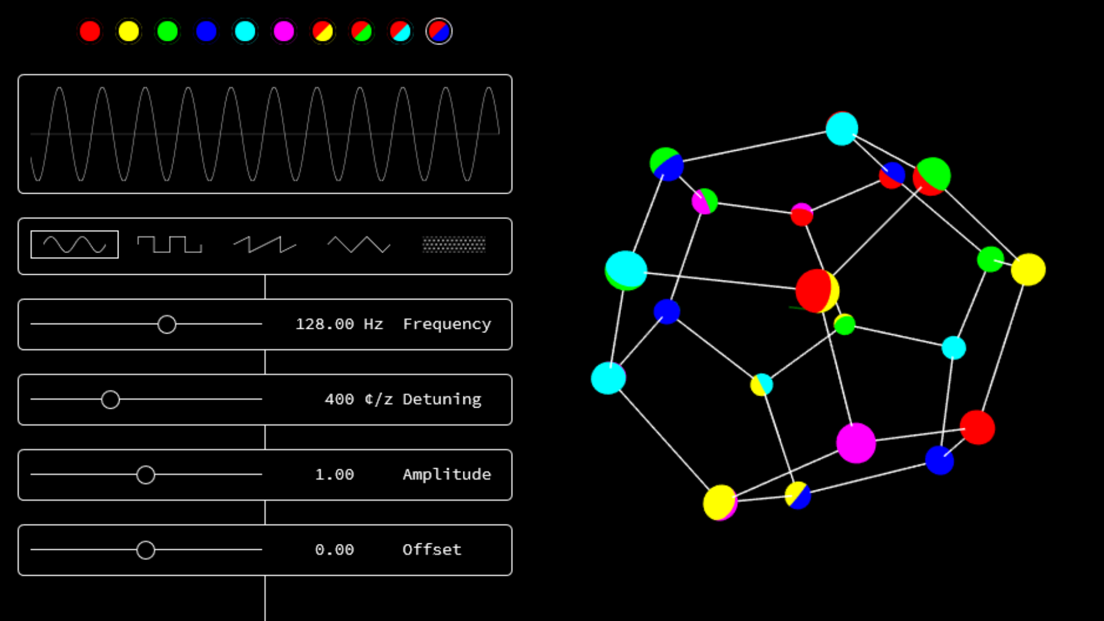
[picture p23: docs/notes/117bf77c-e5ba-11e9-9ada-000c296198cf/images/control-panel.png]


* Bamboo edge
:PROPERTIES:
:CUSTOM_ID: edge
:END:

| Component                      | QTY |
|--------------------------------+-----|
| Bambo pole                     |   1 |
| (Light pipe, acrylics ⌀ 10 mm) |   1 |
| Quick-connect, female, brass   |   2 |

*Update:* The light pipe is not needed if the cane is straight and there is a
clear line of sight through it.

#+CAPTION: Prototype
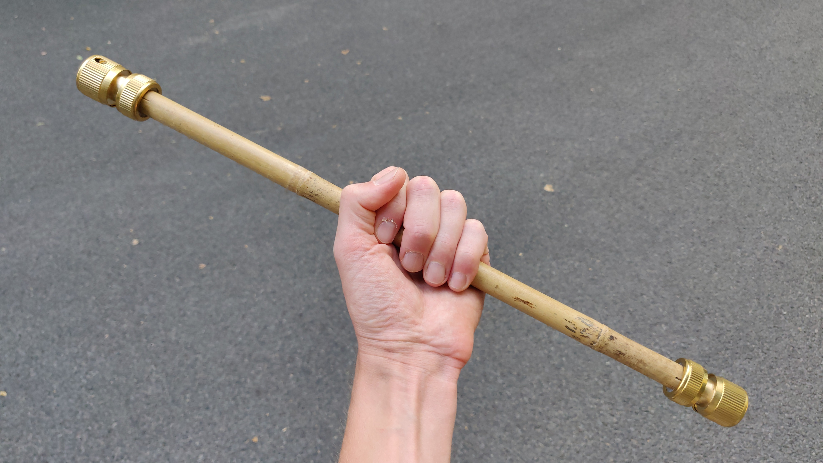
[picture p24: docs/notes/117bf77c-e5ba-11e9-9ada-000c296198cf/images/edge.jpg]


** Production
:PROPERTIES:
:CUSTOM_ID: edge-production
:END:

Steps:

- Perforate all segments, so that light can pass through pole.

- Fire proof wood (spray).

- Insert light pipe.

- Prepare ends of pole for inside and outside diameter matching quick-connect.

- Mount quick-connects onto ends and secure them with epoxy.

#+CAPTION: Dimensions
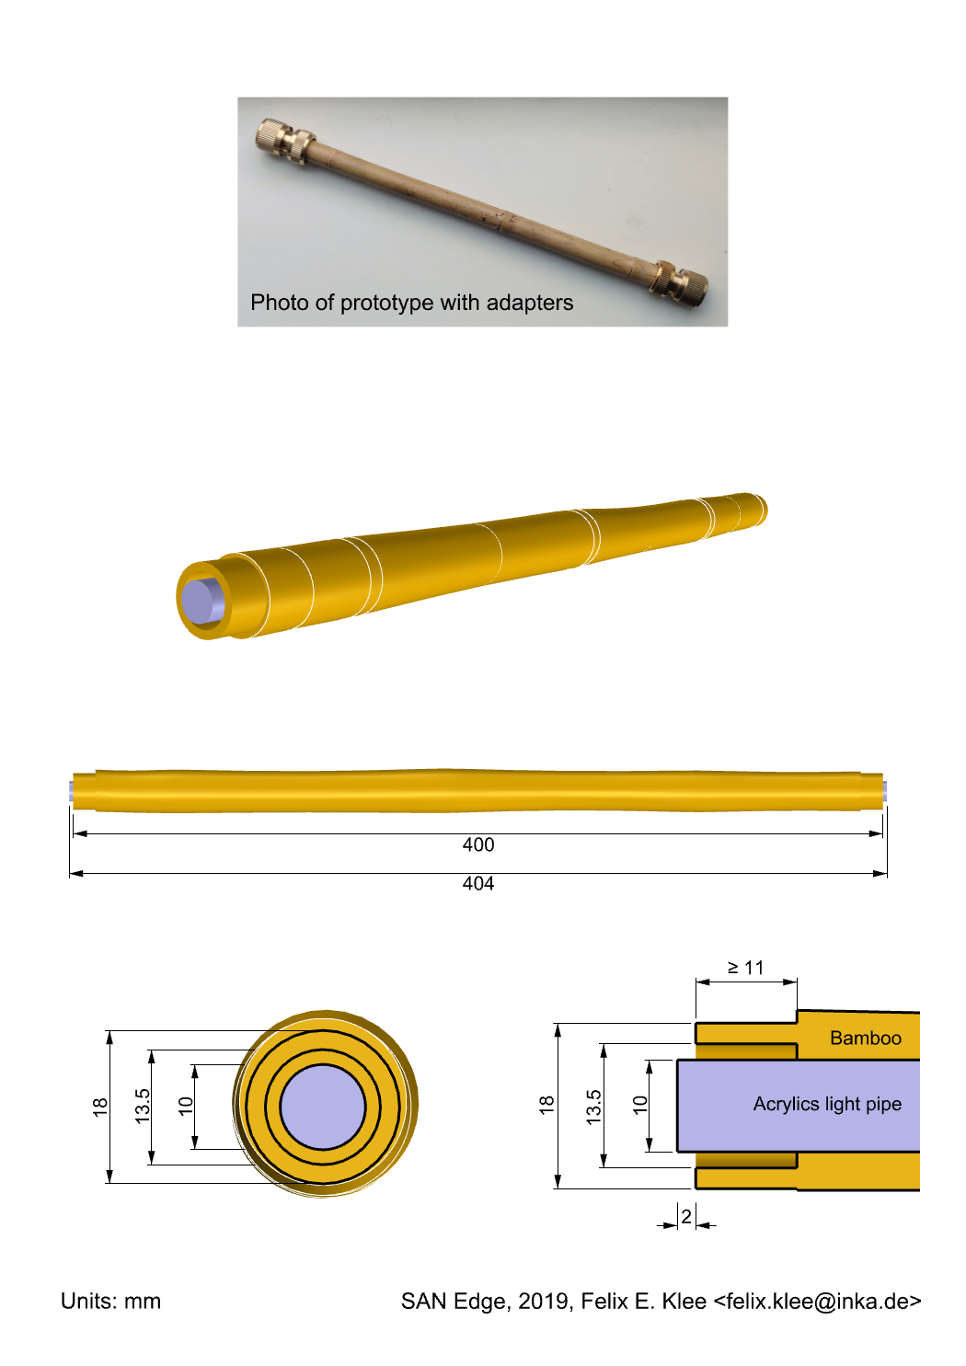
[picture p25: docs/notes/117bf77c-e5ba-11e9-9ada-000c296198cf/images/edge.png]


#+CAPTION: 3/4″ garden hose quick-connect


#+CAPTION: 3/4″ garden hose quick-connect: details


** Material cost estimate

|   | Item                    | Cost / Item | Quantity | Cost / HKD |
|---+-------------------------+-------------+----------+------------|
|   | 500 × 20 mm bamboo cane |       20.00 |        1 |      20.00 |
|   | quick-connect           |        9.00 |        2 |      18.00 |
|---+-------------------------+-------------+----------+------------|
| # |                         |             |          |      38.00 |
| ^ |                         |             |          |       cost |
#+TBLFM: @2$5..@II$5=$3*$4;%.02f::$cost=vsum(@2..@-1);%0.2f

Quantity: 50

* Coco node
:PROPERTIES:
:CUSTOM_ID: node
:END:

| Component                  | QTY |
|----------------------------+-----|
| Coconut shell              |   1 |
| Quick-connect, male, brass |   4 |
| Cable tie                  |   4 |
| Addressable RGB LED        |   4 |
| CPU                        |   1 |
| MCU                        |   1 |
| IR transceiver             |   4 |
| Power bank                 |   1 |
| Camera                     |   1 |
| Microphone                 |   1 |
| Accelerometer              |   1 |
| (Speaker)                  |   1 |

#+CAPTION: Non-functional prototype


** Production

- Cut coconut shell in half.

- Consume coconut water and flesh.

- Drill holes for components and for cable ties.

- Fire proof wood.

- Drill holes.

- Cut in half.

- Mount electronics:

  + Mount LEDs, e.g: [[https://kutop.com/5v-ip68-waterproof-50-nodes-ws2811-ic-rgb-led-pixel-module-string.html][5V IP68 waterproof 50 nodes WS2811 RGB LED]]

  + Mount quick-connects onto shell and secure them with epoxy.

  + Prepare controllers and IR transceivers.

  + Mount IR transceivers in quick-connects.

  + Mount camera and microphone onto shell. (plus maybe speaker)

  + Mount controller and battery into shell and solder connections.

#+CAPTION: Rotating shell with holes


#+CAPTION: Hole positions


#+CAPTION: 3/4″ garden hose quick-connect


** Material cost estimate

|   | Item             | Cost / Item | Quantity |   Cost |
|---+------------------+-------------+----------+--------|
|   | Coconut          |       15.00 |        1 |  15.00 |
|   | quick-connect    |        9.00 |        4 |  36.00 |
|   | Raspberry Pi 0   |      120.00 |        1 | 120.00 |
|   | microSD card     |       40.00 |        1 |  40.00 |
|   | Arduino Pro Mini |       50.00 |        1 |  50.00 |
|   | PCB(s)           |       40.00 |        1 |  40.00 |
|   | Components       |       50.00 |        1 |  50.00 |
|   | Camera           |      150.00 |        1 | 150.00 |
|   | Speaker          |       40.00 |        1 |  40.00 |
|   | Battery          |      150.00 |        1 | 150.00 |
|---+------------------+-------------+----------+--------|
| # |                  |             |          | 691.00 |
| ^ |                  |             |          |   cost |
#+TBLFM: @2$5..@II$5=$3*$4;%.02f::$cost=vsum(@2..@-1);%0.2f

Quantity: 25

** Requirements for controller:

- Transmit ID and port numbers to neighboring nodes via IR transceivers.

- Receive IDs and port numbers from neighboring nodes via IR transceivers.

- Send information who neighbors who to brain, e.g. via WiFi.

- Low priority: Transmit audio and camera stream to brain.

- Low priority: Receive audio stream from brain and output it.

Camera, speaker, and microphone: low priority

Possible CPUs:

- Raspberry Pi 0 (lots of power, full Linux, can program the MCU directly,
  author knows it)

- ESP-EYE (cheap, with cam and mic on board, but limited power, MCU may need to
  be programmed separately)

Possible MCUs:

- STM32 Black Pill

- Arduino Pro Mini 328p (sufficient, used in SAN desktop system)

- /something that has an accelerometer already on board/

#+CAPTION: Components
[[./images/node.svg]]

** IR transceiver

| Component            | QTY |
|----------------------+-----|
| Board, ⌀ 25.7 mm     |   1 |
| Capacitor            |   1 |
| Resistor             |   1 |
| IR-LED               |   1 |
| Sensor (38 ∨ 56 kHz) |   1 |
| Connector            |   1 |

#+CAPTION: Components
[[./images/transceiver.svg]]

** Power bank

Example product:

- Product page: [[https://www.alibaba.com/product-detail/Single-usb-mini-2600mAh-battery-charger_60406994470.html][Single usb mini 2600mAh battery charger portable cell phone
  power bank]]

- Dimensions (cylindrical): 91 × 21.8 mm

- Weight: 90 g

The power bank could be positioned on top of a foam pad and fixed with cable
ties.  Like that it’s easy to replace.

[[./images/power-bank.svg]]

Alternatively, the power bank could be positioned loosely, with padding stuffed
around it, filling the entire coconut.

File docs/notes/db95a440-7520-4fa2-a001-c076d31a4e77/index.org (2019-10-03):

#+HTML_HEAD: <style>img{max-width:100%}.figure-number{display:none}</style>

#+TITLE: SAN: PCB Design for Desktop System

* Objectives

- Find outline for PCBs.

- Check the schematic designed with KiCad.

- Create a manufacturing ready board layout.

- Optimize price and manufacturing time.

* 3D mockup

#+BEGIN_EXPORT html
<iframe allowfullscreen id="irisModel" width="100%" height="600px"
src="mockup.iris/index.html" frameBorder="0"></iframe>
#+END_EXPORT

Via the top left menu, layers can be turned off to reveal the inside
of the sphere.  Only certain large components are part of the mockup.
The 3D mockup has been created with the [[https://mcneel.github.io/Iris/][Iris plugin]] from the Rhino 3D
model file [[./mockup.3dm][mockup.3dm]].

- The diameter of the sphere is 50 mm.

- Only larger components have been included.

- There are two PCBs in order to get the LEDs in the correct
  positions.

- The top USB connector is abused for interfacing with an FTDI.  This
  is to easily be able to update the firmware.

* Schematic
:PROPERTIES:
:CUSTOM_ID: schematic
:END:

#+BEGIN_EXPORT html
<img alt="Node circuit" src="./images/node.svg">
#+END_EXPORT

#+BEGIN_EXPORT html
<img alt="Top hemisphere circuit" src="./images/top.svg">
#+END_EXPORT

#+BEGIN_EXPORT html
<img alt="Bottom hemisphere circuit" src="./images/bottom.svg">
#+END_EXPORT

This is a snapshot of the schematic.  The most recent version of the
schematic can be found in the KiCad project [[https://github.com/feklee/san/tree/master/nodes/pcb/node][node]] in the SAN repo on
GitHub.

* Seeed Studio
:PROPERTIES:
:CUSTOM_ID: seeed
:END:

As assembly house [[https://www.seeedstudio.com/][Seeed Studio]] has been chosen. Capabilities of the
/Seeed Fusion One-Stop PCB Assembly Service:/

- [[https://www.seeedstudio.com/fusion.html][Fusion overview]] (/Passive Components as small as 01005(0402)
  package/)

- [[https://www.seeedstudio.com/prototype-pcb-assembly.html][Seeed Studio Fusion PCB Assembly]] (with section about /PCB assembly
  capabilities/)

- [[http://support.seeedstudio.com/knowledgebase/articles/447362-fusion-pcb-specification][Fusion PCB Specification]] (incl. Gerber requirements and tolerances)

- [[http://support.seeedstudio.com/knowledgebase/articles/457797-fusion-pcba-specification][Fusion PCBA Specification]]

- [[http://www.seeedstudio.com/blog/2017/05/15/component-layout-considerations/][Component layout considerations – PCB DFM Part 4]]

- [[http://support.seeedstudio.com/knowledgebase/topics/63002-fusion-technical-faq][Fusion Technical FAQ?]] (with panelization rules and more)

- [[https://www.seeedstudio.com/fusion_pcb.html][Upload form]] (with selectable /Trace Width / Spacing/ and /Minimum
  Drill Hole Size/)

** OPL
:PROPERTIES:
:CUSTOM_ID: seeed-opl
:END:

Seeed keeps components in stock for quick production time. These are
listed in the [[https://www.seeedstudio.com/opl.html][Open Part Library]]. Notes:

- The OPL is split into two libraries: Selected can be the /Seeed OPL/
  or the /Shenzhen OPL/, which is based on a [[https://www.seeedstudio.com/blog/2018/12/04/just-what-you-wanted-for-xmas-introducing-the-new-shenzhen-open-parts-library-with-over-10000-parts/][partnership]] with the
  HuaQiang Group.

- For the /Seeed OPL/ there is a corresponding [[https://github.com/Seeed-Studio/OPL_Kicad_Library][KiCad library]]
  available.

- For the project, only components from the OPL will be used. (Let’s
  hope components in the Seeed OPL are in stock.)

** Inside

The author of this document visited Seeed Studio in Shenzhen as part
of Mitch Altman’s 2017 [[https://www.noisebridge.net/wiki/NoisebridgeChinaTrip7][Hacker Trip to China]].

#+BEGIN_EXPORT html
<a data-flickr-embed="true"  href="https://www.flickr.com/photos/maltman23/38194661961/in/photostream/" title="Shenzhen, Oct-2017"><img src="https://farm5.staticflickr.com/4554/38194661961_6226e6565f_c.jpg" width="800" height="533" alt="Shenzhen, Oct-2017"></a><script async src="//embedr.flickr.com/assets/client-code.js" charset="utf-8"></script>
#+END_EXPORT

* Ideas
:PROPERTIES:
:CUSTOM_ID: ideas
:END:

- Summary of design suggestions by Herbert (May 21 2019 CEST, by
  email):

  + Replace 5V LDO with buck converter: LTC3129 (200mA) or LTC3130
    (600mA)

  + Replace 3.3V LDO with buck converter: PS82740A (via 5V rail)

  + Replace BAT54 Schottky barrier diode with more efficient
    alternative: PMEG2010

  + To avoid interference, decouple the AVCC (5V) and AREF (3.3V)
    inputs each using a ferrite bead plus separate capacitor.

- Replace the Mini USB Type B connector with a Tag-Connect interface,
  sticking out of the shell behind the battery.

  Then it may be possible to make both boards the same size.

- Replace NeoPixel THT LEDs with SMD LEDs shining sidewards.

- The legs of the first LED may touch the resistor connecting the data
  pin. Fix that.  On the other hand, it’s nicer if LEDs are soldered
  on the bottom side.  Then they’re closer to the middle of the
  sphere.

- Use a separate MCU for controlling the LEDs. This takes off load
  from the main MCU, allowing the LED colors to be changed without
  taking away too many clock cycles otherwise needed for communication
  between nodes. Also a separate MCU may have enough ports to drive
  the LEDs directly.

  Alternatively, use a dedicated LED driver.

  Disadvantage: FFC needs more wires.

- Move the Tag-Connect interface for burning the bootloader to the
  back. This saves space on the front.

- Use a Tag-Connect interface for plugs with legs. (additional holes
  necessary)

- Shell:

  + Make flat top thicker to avoid light showing internals.

  + Give a 0.25 mm additional space for boards in flat top, so that
    sphere screws together seamlessly.

  + E.g. by using pins, enforce in which orientation the two
    hemispheres have to be assembled.

* Source of 3D compontents

- BK-912: [[http://www.memoryprotectiondevices.com/3d/download.php?pn=BK-912][=BK-912.STEP=]]

- APFA3010LSEEZGKQBKC: [[http://www.kingbrightusa.com/images/catalog/3D/STEP/APFA3010.STEP][=APFA3010.STEP=]]

- Molex PicoBlade 0533980271: [[https://www.molex.com/pdm_docs/stp/53398-0271_stp.zip][=533980271.stp=]]

- TE AMP Mini CT 292228-2: [[https://www.te.com/commerce/DocumentDelivery/DDEController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][=c-0292228-02-a-3d.stp=]]

- Amphenol 10118193-0001LF: [[https://cdn.amphenol-icc.com/media/wysiwyg/files/3d/s10118193.zip][=10118193-0001lfc.stp=]]

- Amphenol SFW8R-2STE1LF: [[https://cdn.amphenol-icc.com/media/wysiwyg/files/3d/ssfw08r_2_4stlf.zip][=ssfw08r_2_4st_lf.stp=]]

- ATMega 328P-AU: [[https://digikey.ultralibrarian.com][=32A.step=]] (Ultra Librarian for Digi-Key)

- BNC connector: [[https://www.amphenolrf.com/031-221-rfx.html][=31-221-RFX.stp=]]

- Hirose FH12-6S-0.5SH(55): [[https://www.hirose.com/product/document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][=FH12-6S-0.5SH.stp=]]

- JST 2mm: [[https://raw.githubusercontent.com/KiCad/kicad-packages3D/master/Connector_JST.3dshapes/JST_PH_B2B-PH-K_1x02_P2.00mm_Vertical.step][=JST_PH_B2B-PH-K_1x02_P2.00mm_Vertical.step=]]

- Molex PicoBlade: [[https://www.molex.com/pdm_docs/stp/53047-0210_stp.zip][=530470210.stp=]]

- Mini-USB connector: [[https://kicad.github.io/download/packages3d/Connector_USB.3dshapes.7z][=USB_Mini-B_Lumberg_2486_01_Horizontal.step=]]

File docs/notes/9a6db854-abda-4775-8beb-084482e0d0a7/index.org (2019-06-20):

#+HTML_HEAD: <style>img{max-width:100%}.figure-number{display:none}</style>

#+TITLE: SAN: AI Based Visual Self Awareness

* Abstract

Two or maybe four cameras are put into each node.  The cameras see the
environment and in particular the connections to other nodes.  Camera
information is sent to the main computer e.g. via WiFi.

The network configuration plus camera images is used as training data
for machine learning.  Thereby the algorithm learns to infer the
network configuration from the camera images.

It is no longer needed for the nodes to communicate.

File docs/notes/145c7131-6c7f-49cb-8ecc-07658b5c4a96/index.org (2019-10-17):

#+HTML_HEAD: <style>body{max-width:42em}img{max-width:100%}.figure-number{display:none}</style>

#+TITLE: SAN: Location Optimizer

* Abstract

The /location optimizer/ takes all the data that is available and
guesses the locations of the nodes in space.

Input:

- which node is connected to which node and on which port,

- tilt angles of nodes (optional).

Output:

- locations of the nodes in space,

- tilt angle of spheres for display (optional).

The location optimizer does its calculations under the assumption
that:

- the length of a connection is 1,

- the angle between connections is the tetrahedral angle (≈ 109.5°).

Note that the information in this document is only relevant for the
version of SAN that was current at the time of publication.

  #+CAPTION: Dodecahedron built by two little girls at the end of Maker Faire Rome: Convergence successful!
  

See also:

- [[https://feklee.github.io/san/notes/9a6db854-abda-4775-8beb-084482e0d0a7/][AI Based Visual Self Awareness]], a completely different approach

- Molecular conformation

* Nodes

  #+CAPTION: Geometry of a node with ports 1–4
  

Properties of a node:

- A node may also be called a /sphere/, referring to the physical
  elements in the SAN construction kit.

- There is one special node, the root node:

  + It connects the computer to the network.

  + It has one USB port that connects to the computer.

  + It has only one port: 1

  + It’s ID is: ~^~

- Non-root nodes have four ports: 1, 2, 3, and 4

- Each non-root node has a unique ID: A–Z

- A node’s /axis/ is relevant if there is information about its tilt
  angle. The tilt angle is measured by an accelerometer. As of this
  writing there is only one sphere that contains an accelerometer.

* Genetic algorithm for location optimization

** Summary

A genetic algorithm is used to approximate the positions of the points
in space. This algorithm is called /location optimizer./ After
optimization, ideally all neighboring nodes have a distance of 1, and
the angles between the connecting edges match those on the
spheres. The algorithm, however, is flexible enough to find solutions
even if distances or angles have been violated. See examples below.

** Steps

1. /Initialize:/ Generate a population of $n$ individuals. Each
   individual $i$ is described by a chromosome $X_i$. A chromosome
   contains a list of coordinates. The coordinates describe a
   distribution of points in space. Initially the coordinates are
   chosen randomly.

   Example population for a network composed of nodes $C$, $B$, and
   $D$:

   |       | $x_C$ | $y_C$ | $z_C$ | $x_B$ | $y_B$ | $z_B$ | $x_D$ | $y_D$ | $z_D$ |
   |-------+-------+-------+-------+-------+-------+-------+-------+-------+-------|
   | $X_1$ | -0.87 | -0.59 |  0.51 |  0.01 | -0.18 |  0.92 | -0.88 | -0.45 | -0.61 |
   | $X_2$ |  0.14 |  0.39 |  0.37 |  0.30 | -0.61 | -0.25 |  0.40 |  0.21 |  0.75 |
   | $X_3$ |  0.40 | -0.54 |  0.00 | -0.43 |  0.94 |  0.29 |  0.37 |  0.76 | -0.74 |
   | …     |       |       |       |       |       |       |       |       |       |
   | $X_n$ |  0.08 | -1.00 |  0.71 | -0.68 | -0.26 |  0.33 | -0.64 |  0.94 |  0.95 |

2. /Reproduce:/

   1. /Pair:/ Randomly select pairs of individuals. These individuals
      will act as parents in the next step.

      Example pair: $(X_3, X_1)$

   2. /Create offspring./ For each pair of parents:

      1. /Crossover:/ Form a child chromosome by taking one part of
         the chromosome from the first parent and the other part from
         the second parent.

         Child created from a crossover of the above example pair:

         | $X_3$: $x_C$ … $x_D$                 | $X_1$: $y_D$ … $z_D$ |
         |--------------------------------------+----------------------|
         | /                                    | <                    |
         | 0.40 -0.54 0.00 -0.43 0.94 0.29 0.37 | -0.45 -0.61          |

         The location of the crossover is random. More than one
         crossover may happen, i.e. switching multiple times from the
         chromosome of one parent to that of the other.

      2. /Mutate:/ Randomly change coordinates in the child
         chromosome.

         Example mutation of the above child:

         0.40 -0.54 *-1.50* -0.43 0.94 0.29 0.37 -0.45 *0.40*

3. /Find fitness:/ For each child determine how close the coordinates
   in the chromosome are to an optimal distribution. An optimal
   distribution is one where:

   - the distance between each two neighboring nodes is 1,

   - the angle between each two connections from one node is the
     tetrahedral angle.

   The deviation to the optimal distribution is quantified as fitness
   and assigned to each child.

4. /Natural selection:/ Create a new population by combining:

   - the $n - 1$ best children,

   - the best individual from the previous generation.

5. /Visualization:/ Render the best individual in the new population
   on screen.

6. /Iterate:/ go to step 2.

** Problem

Genetic algorithms tend to get stuck in local minima. In that case all
individuals have converged close to the same non-optimal
solution. Mutation of single coordinates worsen the fitness of an
individual. Therefore, differing individuals don’t carry over to the
next generation. Evolution has stopped.

** Fitness

Fitness is a measure for the deviation from the optimum. But how do we
calculate the deviation if we don’t know the optimum? Let’s see!

The idea is to calculate the deviation from the optimum for each node,
then sum all deviations. What follows is an example for node $A$ with
a full set of neighbors, $B$, $C$, $D$, and $E$.



In this example, the connections for node $A$ are:

- Connection 1: port 4 connected to node $B$ (yellow)

- Connection 2: port 1 connected to node $E$ (blue)

- Connection 3: port 3 connected to node $D$ (aqua)

- Connection 4: port 2 connected to node $C$ (lime)

*** Deviation of first neighbor

Correct neighbor locations lie on a sphere of radius 1. As the
location of the /expected neighbor/ $1'$, we take the point that is
closest to the location of the existing neighbor $1$ (deviation
highlighted in red):



The deviation is the difference between the two locations:

$D_{A,1} = 0.50$

*** Deviation of second neighbor

Correct neighbor locations are at the tedrahedral angle to the edge
connecting the node and its first expected neighbor $1'$. In addition,
correct neighbor locations are required to have a distance of 1 from
the center. Therefore, the set of all correct locations lies on a
circle. As the location of the expected neighbor $2'$ we select from
this set the point that is closest to the exising neighbor $2$.



Deviation:

$D_{A,2} = 0.28$

*** Deviations of third and fourth neighbor

Based on the locations of the first two expected neighbors $1'$ and
$2'$, we can calculate the locations of the remaining expected
neighbors $3'$ and $4'$.



Deviations:

$D_{A,3} = 0.49, D_{A,4} = 0.63$

*** Total deviation

Now we can calculate the total deviation of all the neighbors of the
node:

$D_A = D_{A,1} + D_{A,2} + D_{A,3} + D_{A,4} = 1.90$

After the deviation has been calculated for every node, the total
deviation can be calculated. For a network with nodes $A$, $B$, $C$,
$D$, and $E$ that would be:

$D = D_A + D_B + D_C + D_D + D_E$

To get the fitness $F$ of the current chromosome, we simply reverse
the sign:

$F = -D$

As the value of the deviations is negative, it holds that: The higher
the fitness, the closer the individual is to an optimal solution.

*** Note about the positions of the third and fourth neighbor

Note that for calculating the positions of connections 3 and 4, the
position of the ports is relevant. Take a look at the following two
structures. They are not identical!



** Alternative fitness proposal

The following proposal creates the fitness based on the sum of
independent terms. The terms may possibly be multiplied by
weights. With the first two terms, this fitness has been used as cost
function in David’s [[https://github.com/davidblitz/san-optimizer][San-Optimizer]] based on the /gradient descend/
algorithm. Another suggestion is to use the /conjugate gradient
method./

*** Distance

\begin{equation}
F_D = \sum_{n=1}^N (l_n^2 - 1)^2
\end{equation}

Where:

- $N$: number of all edges

- $l_n$: length of edge $n$

$1$ is the expected distance.

*** Angle

\begin{equation}
F_A = \sum_{n=1}^N \sum_{i=1}^{I_n} \sum_{j=1\\j≠i}^{I_n} (\vec{v}_{n,i}
⋅ \vec{v}_{n,j} + ⅓)^2
\end{equation}

Where:

- $N$: number of nodes

- $I_n$: number of neighbors attached to node number $n$

- $v_{n,i}$: vector connecting node number $n$ to neighbor number $i$

$-⅓$ is the cosine of the required tedrahedral angle.

Note that the vectors are not normalized. Nevertheless optimization
works in David’s implementation.

*** Chirality

\begin{equation}
F_C =
    \sum_{n=1}^L
    \Big((\vec{v}_{n,1}^L × \vec{v}_{n,2}^L) ⋅ \vec{v}_{n,3}^L -
    cos\big(\frac{π}{2} - \frac{1}{2} arccos(-⅓)\big)\Big)^2 + \\
    \sum_{n=1}^R
    \Big((\vec{v}_{n,1}^R × \vec{v}_{n,2}^R) ⋅ \vec{v}_{n,3}^R -
    cos\big(\frac{π}{2} + \frac{1}{2} arccos(-⅓)\big)\Big)^2
\end{equation}

Where:

- $L$: number of nodes with left handed chirality

- $R$: number of nodes with right handed chirality

- $v_{n,i}^{L/R}$: normalized vector connecting left/right handed node
  number $n$ to its neighbor number $i$

Only nodes with at least three neighbors are included. The other nodes
don’t have chirality.

*** Tilt

Some nodes provide tilt information by means of an accelerometer, the
tilt angle $α$. Tilt is measured against the z-axis $\vec{z}$. To work
with tilt, we introduce an additional unknown, the tilt axis
$\vec{a}_n$. For node number $n$ we get the term:

\begin{equation}
F_{T,n} = (\vec{z} ⋅ \vec{a}_n - cos(α))
\end{equation}

For visualization, the colored hemispheres of a node are oriented
along the tilt axis.

*** Orientation

With tilt, there is a constraint on the orientation of
connections. Relative to the tilt axis, connections on ports 1 and 2
are oriented at half tetrahedral angle $τ$ whereas connections on
ports 3 and 4 are oriented at $π/2 - τ$. The fitness term is $F_O$.

*** Total fitness

The total fitness is:

\begin{equation}
F = -(w_D F_D + w_A F_A + w_C F_C + w_T F_T + w_O F_O)
\end{equation}

Where $w_i$ are weights.

* Simulation

Assembling the structure can be simulated. This is useful for testing
the location optimizer without the physical construction kit.

Setup:

1. Install Node.js and the Yarn package manager.

2. Clone the SAN repository from: [[https://github.com/feklee/san/]]

3. Install all necessary dependencies and build the frontend (on
   Windows call ~rollup.cmd~ instead of ~rollup~):

   #+BEGIN_SRC shell
   $ cd webapp
   $ yarn install
   $ ./node_modules/.bin/rollup --config
   #+END_SRC

4. Start the simulation:

   #+BEGIN_SRC shell
   yarn start simulate
   #+END_SRC
   
5. Open the SAN web app: http://localhost:8080

   

   To navigate in 3D in the canvas on the left side, use the mouse.

6. Go back to the command line and connect a node to the root node:

   #+BEGIN_SRC text
   +^1C1
   #+END_SRC

   This connects port ~C1~ (port 1 on node C) with ~^1~ (port 1 on the
   root node). The result is immediately visible in the web app.

   

   On the top right side you see an adjacency matrix. The numbers in
   the matrix refer to the connected ports. On the bottom right side
   you see a log of the information that the webapp receives from the
   structure. Each line begins with a timestamp. The circle on the
   right means that there is no information about a tilt angle for the
   connected node.

7. Add additional nodes:

   #+BEGIN_SRC text
   +C2B1
   +B3D4
   #+END_SRC

   This connects ~B3~ (port 3 on node B) to ~C2~ and ~D4~ to ~B3~.

   

* Experimentation

For experimentation, custom locations may be assigned to nodes.

1. Open the SAN web app.

2. Make sure that you see the network that you want to work with.

3. Open your browser’s JavaScript console.

4. Stop the location optimizer:

   #+BEGIN_SRC js
   locationOptimizer.stop();
   #+END_SRC

5. Assign the locations, for example:

   #+BEGIN_SRC js
   locationOptimizer.setLocations({
       A: [0, 0, 0],
       B: [1, 0, 0],
       C: [1, 1, 0],
       D: [0, 1, 0]
   });
   #+END_SRC

6. Optionally, update the locations in the location optimizer and
   resume optimization:

   #+BEGIN_SRC js
   locationOptimizer.update();
   locationOptimizer.run();
   #+END_SRC

   Caution: If your locations cannot compete with the locations in the
   current population, you will not see them in the next
   generation. They will disappear immediately.

* Examples

** 1:1

Just two nodes are connected.

*** Input

Simulation:

#+BEGIN_SRC text
+^1A1
+A2B1
#+END_SRC



Adjacency matrix (numbers are ports): [[./data/1-1-adjacency.tsv][1-1-adjacency.tsv]]

*** Example solution 



Coordinates: [[./data/1-1-coordinates.tsv][1-1-coordinates.tsv]]

** 1:4

One node has all of its four neighbors connected.

*** Input

Simulation:

#+BEGIN_SRC text
+^1B2
+B1A1
+A2C1
+A3D1
+A4E1
#+END_SRC



Adjacency matrix (numbers are ports): [[./data/1-4-adjacency.tsv][1-4-adjacency.tsv]]

*** Example solution 



Coordinates: [[./data/1-4-coordinates.tsv][1-4-coordinates.tsv]]

** Hexagon

This is the smallest loop that can be built without violating the
tetrahedral angles.

*** Input

Simulation:

#+BEGIN_SRC text
+^1A1
+A2B1
+B2C1
+C2D1
+D2E1
+E2F1
+F2A3
#+END_SRC



Adjacency matrix (numbers are ports): [[./data/hexagon-adjacency.tsv][hexagon-adjacency.tsv]]

*** Example solution



Coordinates: [[./data/hexagon-coordinates.tsv][hexagon-coordinates.tsv]]

** Pentagon

Note that the interior angles of a pentagon are 108°. That is close to
but not identical to the tetrahedral angle of 109.5°. Nevertheless the
algorithm is able to approximate a solution. Even for nodes connected
in a triangle it finds a solution!

*** Input

Simulation:

#+BEGIN_SRC text
+^1A1
+A2B1
+B2C1
+C2D1
+D2E1
+E2A3
#+END_SRC



Adjacency matrix (numbers are ports): [[./data/pentagon-adjacency.tsv][pentagon-adjacency.tsv]]

*** Example solution



Coordinates: [[./data/pentagon-coordinates.tsv][pentagon-coordinates.tsv]]

** Dodecahedron

The dodecahedron consists of twelve pentagon sufaces. There are 20
unknown edges, i.e. nodes in the network. This means 60 variables have
to be found.

*** Input

Simulation:

#+BEGIN_SRC text
+^1A4
+A1B2
+A2E1
+A3F1
+B1C2
+B3H1
+C1D2
+C3J1
+D1E2
+D3L1
+E3N1
+F2O2
+F3G3
+G1P1
+G2H2
+H3I3
+I1Q1
+I2J2
+J3K3
+K1R1
+K2L2
+L3M3
+M1S1
+M2N2
+N3O3
+O1T1
+P2T3
+P3Q2
+Q3R2
+R3S2
+S3T2
#+END_SRC



Adjacency matrix (numbers are ports): [[./data/dodecahedron-adjacency.tsv][dodecahedron-adjacency.tsv]]

*** Example solution



Coordinates: [[./data/dodecahedron-coordinates.tsv][dodecahedron-coordinates.tsv]]

*** Example bad solution

In most runs, at least nine out of ten times, the genetic algorithm
does not find a good solution. It gets stuck in a local minimum.



** Dodecahedron with tilt angles

Tilt angles provide additional information. The idea is to reduce the
space of unknown variables from 60 to 40, thereby making it easier to
find a solution. On the other hand, calculation of fitness is more
cumbersome and, at least in the current implementation, more time
consuming.

Results have been mixed. In fact it looks like convergence now is
almost unachievable.

Another purpose for tilt information is to get a more accurate
represantation of what the user actually built. Without tilt
information, for example, the displayed structure may be upside down
compared to what the user sees sitting on the table.

*** Input

Simulation (~/A92~ sets the tilt angle of node $A$ to 92°):

#+BEGIN_SRC text
+^1A4
+A1B2
+A2E1
+A3F1
+B1C2
+B3H1
+C1D2
+C3J1
+D1E2
+D3L1
+E3N1
+F2O2
+F3G3
+G1P1
+G2H2
+H3I3
+I1Q1
+I2J2
+J3K3
+K1R1
+K2L2
+L3M3
+M1S1
+M2N2
+N3O3
+O1T1
+P2T3
+P3Q2
+Q3R2
+R3S2
+S3T2
/A92
/B92
/C92
/D92
/E92
/F107
/G73
/H107
/I73
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
#+END_SRC

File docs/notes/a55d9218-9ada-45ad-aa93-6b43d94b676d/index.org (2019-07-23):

#+HTML_HEAD: <style>body{max-width:42em}img{max-width:100%}.figure-number{display:none}</style>

#+TITLE: SAN: Audio

* Introduction

SAN is a construction system for architectural structures that
interact with the environment visually and auditory.  This document
discusses the auditory part: /How can an architectural structure be a
musical instrument?/

#+CAPTION: Dodecahedron built by two little girls at the end of Maker Faire Rome.  Notice the visualization in the background: The structure understands how it is assembled.


* Approaches

What follows is a discussion of vairous approaches to turning the
structure into sound or even have it generate music.

** Sound of molecular vibrations
:PROPERTIES:
:CUSTOM_ID: sound
:END:

*** Idea

/Treat the structure as a molecule made up of carbon atoms.  Turn
molecular vibrations into a sound./

Like the spherical building elements of SAN, carbon atoms have four
bonds arranged in tetrahedral symmetry.  Molecules can be made to
vibrate.  These [[https://en.wikipedia.org/wiki/Molecular_vibration][molecular vibrations]] have different frequencies which
together make up a spectrum:

#+BEGIN_EXPORT html
<img alt="Example spectrum" src="./images/spectrum.svg">
#+END_EXPORT

#+CAPTION: Molecule with six atoms in one of its 12 possible vibration modes


*** Examples

Scientists and musicians have explored turning molecular spectra into
sound:

- [[http://www.ejectamenta.com/online-apps/MolecularSounds.html][Molecular Sounds (ejectamenta)]], a keyboard with each key mapped to a
  different molecule and its sound:

  #+CAPTION: Screenshot
  

- Molecular composition based on [[https://en.wikipedia.org/wiki/Nuclear_magnetic_resonance_spectroscopy][NMR spectra]] by [[mailto:falkyx7@gmail.com][Falk Morawitz]]:

  #+BEGIN_EXPORT html
  <iframe width="100%" height="166" scrolling="no" frameborder="no" allow="autoplay" src="https://w.soundcloud.com/player/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"></iframe>
  #+END_EXPORT

  See also his 2016 talk [[https://zkm.de/de/media/video/stroemungen-falk-morawitz][Sonification of nuclear magnetic resonance in
  ½ spin systems: An overview]] at ZKM Karlsruhe.

*** Calculation of vibrations

There are many ways to calculate molecular vibrations.  Simple
estimates can be done on a piece of paper.  Relatively accurate
results are given by the /harmonic approximation/ where the bonds
between atoms are treated as harmonic oscillators (see the book
[[https://books.google.de/books?id=CPkvsDrPiv0C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][Molecular Vibrations]] by Wilson, Decius, and Cross, 1955).  Then there
are quantum mechanical methods that are ever more accurate and
complex.

To get an idea concerning how different spectra look, the software
Gaussian 09 can be used:

#+BEGIN_EXPORT html
<iframe width="560" height="315" src="https://www.youtube.com/embed/xeWIe1p89k4" frameborder="0" allow="accelerometer; autoplay; encrypted-media; gyroscope; picture-in-picture" allowfullscreen></iframe>
#+END_EXPORT

** Collaborative modular synthesizer
:PROPERTIES:
:CUSTOM_ID: modular-synth
:END:

*** Idea

Each node is module in a big modular synthesizer:

- Using a web UI, users can tweak the properties of individual
  modules.

- Reconnecting nodes updates how the modular synthesizer is patched.

- Master output: There is one root node in the network, which is where
  the structure is connected to the computer.  This root node serves
  as the master output.

*** A module

Each node has several child nodes and one parent node.  By default
each node acts as an oscillator possibly at a base frequency detuned
depending on the node’s position.  All oscillators are simply added.
This makes the structure make sound by default without any user
interaction.

- Inputs: child nodes

- Outputs: parent nodes, or root node (master)

#+CAPTION: Screenshot of a module connected to master, July 23 2019


*** Possible extensions

It could be interesting to give the user a selection of inputs:

- outputs from the neighboring child nodes

- oscillator

- position of the node in space: x, y, z

- color of node

There could be various predefined properties, such as pitch or the
duration of a repeating loop, that the user can attach inputs to.
Also the node could be made freely programmable, perhaps globally for
all nodes at once.

In addition to the sliders, users could be given the option to tap on
number and modify it using text entry.

*** Examples for collaborative synths

- [[https://github.com/CarloCattano/PopularSynth][Popular Synth]] by Carlo Cattano (host of [[https://www.meetup.com/de-DE/spektrum/events/ckdswpyxqbxb][Sonic Code Sessions]] in
  Berlin)

- [[https://youtu.be/56spBAgOYfg?t=1442][Socket Synthesizer]] presented by Steve Kinney at JSConf US 2015

** Sequencer
:PROPERTIES:
:CUSTOM_ID: sequencer
:END:

Idea: /Walk through the molecule, atom by node.  Trigger an action at
each step, such as playing a note associated with node./

Open question: Is there a standard way to walk the atoms of a
molecule?

** Adjacency matrix
:PROPERTIES:
:CUSTOM_ID: matrix
:END:

The adjaceny matrix is visible in the main interface.  Create sound
based on that.

** Neurons

:PROPERTIES:
:CUSTOM_ID: neurons
:END:

Treat SAN as a neural network.  Investigate how pulses are passed
around in a biological neural network.

(idea of Brian / Sonic Code Sessions 02/2019)

** Mood

Ivan Palmegiani pointed out that Science Hack Lab Berlin on June 8
2019 that there is research that certain sound waves affect mood.

This means that mood can be changed according to the structure built.

** Cognimates extension

Stafania suggested on June 17 CEST at Betahaus in Berlin to create an
extension for SAN for her [[http://cognimates.me][Cognimates]] AI teaching platform.  She
outlined that it may be possible to train the AI to create music based
on certain constellations.

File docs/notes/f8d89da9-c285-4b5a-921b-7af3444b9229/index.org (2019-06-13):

#+HTML_HEAD: <style>body{max-width:42em}img{max-width:100%}.figure-number{display:none}</style>

#+TITLE: SAN: Apps

* Introduction

The /Self Aware Network/ (SAN) is a kit for assembling architectural
structures that are aware of themselves.

A structure is comprised of a network.  Nodes communicate and send
information to a computer, which is then able to understand what has
been built.

This information can be used for various purposes:

- visualization of the structure

- modular sound synthesis (see the document [[https://feklee.github.io/san/notes/a55d9218-9ada-45ad-aa93-6b43d94b676d/][SAN: Audio]])

- apps

#+CAPTION: Dodecahedron built by two little girls at the end of Maker Faire Rome.  Notice the visualization in the background: The structure understands how it is assembled.


* App ideas

** Chemistry

An app can give instructions about what to build, and it can give
feedback about what has been built.  Possibly nodes in the network
change color to match atom types.

** Pacman

Gena Shabanov, a software developer suggested at Science Hack Lab
Berlin on June 8 2019 to create a Pacman like game.  A character moves
through the structure, and one needs to adapt it to achieve certain
goals in the game.

There is a problem, though.  As of June 2019, changes to the structure
are not communicated quickly enough to the computer.  So a real-time
action game cannot be implemented.  However, it may be possible to
create a game where one builds a structure, and then something
happens.  For inspiration see for example the game series [[https://en.wikipedia.org/wiki/The_Incredible_Machine_(series)][The
Incredible Machine]].

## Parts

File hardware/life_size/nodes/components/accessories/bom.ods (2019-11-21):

Accessories not on board
Number of nodes: | 25
 | QTY / Node | Total QTY | Already got | Need | URL | Price / RMB / piece | Total price | Source
ESP-EYE | 1 | 25 | 2 | 23 |  | 168.00 | 4,200.00
Cable JST, 100mm: 3-3 (no lock) | 5 | 125 | 0 | 125 |  | 0.21 | 5.25 | not yet
Cable JST, 100mm: 6-NC (no lock) | 1 | 25 | 0 | 25 |  | 0.21 | 5.25 | Taobao
Cable JST, 100mm, 2-NC (no lock) | 2 | 50 | 0 | 50 |  | 0.15 | 3.75 | Taobao
Push button | 1 | 25 | 33 | 0 |  |  | 0.00
Power connector | 1 | 25 | 27 | 0 |  |  | 0.00
Micro USB B connector, to solder | 1 | 25 | 1 | 24 |  | 0.20 | 5.00 | Market
Neopixel LEDs, ⌀12mm, in strands of 4 (!), distance 75 mm (ideally soldered to 3pin JST cable, with lock, 100mm) | 4 | 100 | 1 | 99 | https://www.ebay.com/itm/222676980383 | 4.00 | 100.00
O-ring, 14 x 1,6 mm | 8 | 200 | 0 | 200 |  |  | 0.00
Quick-connect brass, male | 4 | 100 | 0 | 100 |  |  | 0.00
Quick-connect plastic, female | 4 | 100 | 0 | 100 |  |  | 0.00
FFC extender | 1 | 25 | 0 | 25 |  | 5.00 | 125.00
FFC | 1 | 25 | 0 | 25 |  | 6.00 | 150.00
Grand total: |  |  |  |  |  |  | 4,319.25

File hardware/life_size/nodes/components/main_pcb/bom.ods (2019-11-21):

Main PCB (25 pieces)
Number of nodes: | 25
Part/Designator | Manufacture Part Number | QTY / board | Total QTY | Price / RMB / piece | Total Price | Source
B1 | Arduino Pro Mini | 1 | 25 | 12.00 | 300.00 | Market
R1,R2,R3,R4 | 220, 0.5W | 4 | 100 | 0.10 | 10.00 | Market
R5,R7,R9 | 1.7k, 0.5W | 3 | 75 | 0.10 | 7.50 | Market
R6,R8,R10 | 3.3k, 0.5W | 3 | 75 | 0.10 | 7.50 | Market
J7,J8 | JST connector, 2 pins, no lock) | 2 | 50 | 0.36 | 18.00 | Taobao
J1,J2,J3,J4,J5 | JST connector, 3 pins (no lock) | 5 | 125 | 0.41 | 51.25 | Taobao
J6 | JST connector, 6 pins (no lock) | 1 | 25 | 0.44 | 11.00 | Taobao
PCB1 | Charger 03962A | 1 | 25 | 2.00 | 50.00 | Market
PCB2 | Booster SBX | 1 | 25 | 3.00 | 75.00 | Market
BT1 | 2000mAh LiPo 3.7V (65 x 39.5 x 6.11 mm) | 1 | 25 | 16.77 | 419.25 | Factory
 | Battery connector | 1 | 25 |  | 0.00
 | PCB 60x60 mm | 1 | 25 | 106.00 | 2,650.00 | HQB PCB
Total price: |  |  |  |  | 3,599.50

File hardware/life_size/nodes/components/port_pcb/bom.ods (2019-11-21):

Port PCB (100 pieces, small)
Number of boards: | 100
Part/Designator | Manufacture Part Number | QTY / board | Total QTY | Price / RMB / piece | Total price
Q1 | LTR-4206E | 1 | 100 | 0.40 | 40.00 | Market
D1 | TSAL6200 | 1 | 100 | 0.50 | 50.00 | Market
J1 | JST connector, 3 pins (no lock) | 1 | 100 | 0.41 | 41.00 | Taobao
 | PCB | 1 | 100 | 0.84 | 84.00 | HQB PCB
Grand total: |  |  |  |  | 215.00

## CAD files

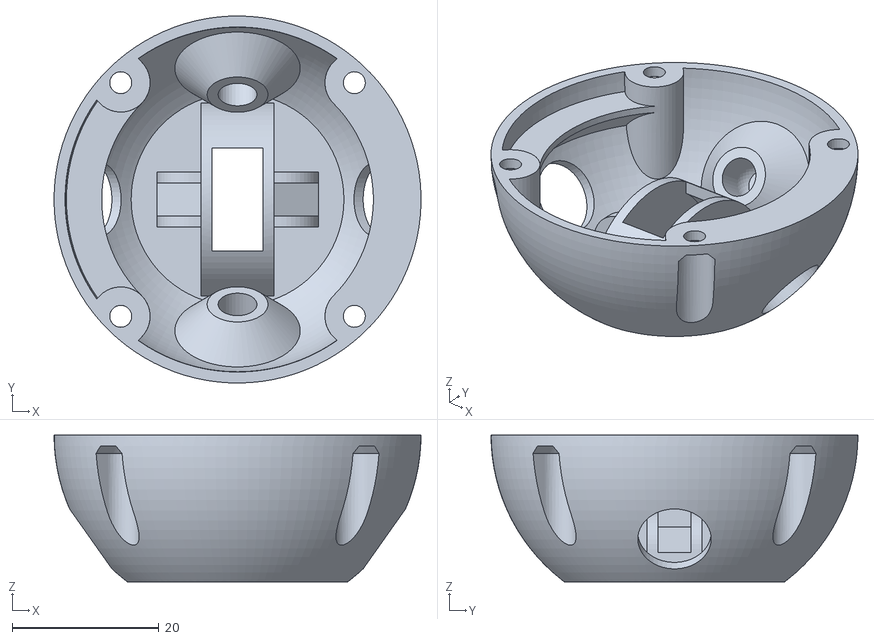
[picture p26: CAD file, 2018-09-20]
hardware/desktop/nodes/hemisphere_optional_bottom.stl
50.0 x 50.0 x 20.0

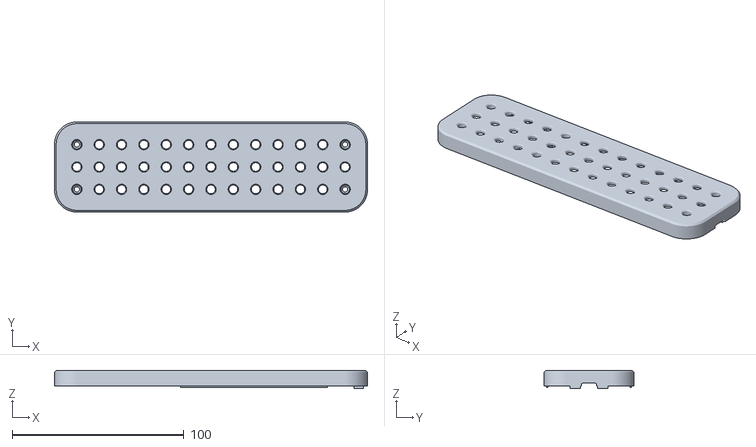
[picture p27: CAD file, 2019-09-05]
hardware/desktop/wifi_root_node/case_top.stl
182.0 x 52.4 x 10.6

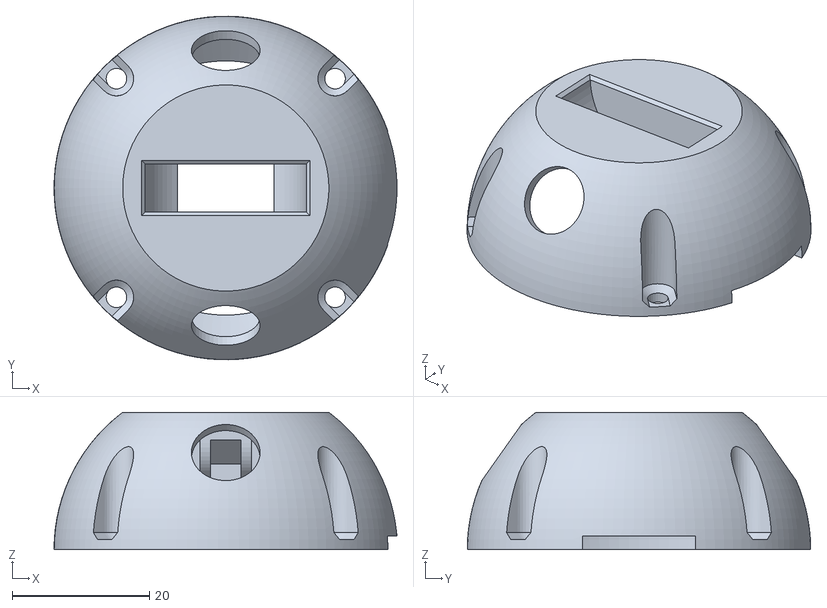
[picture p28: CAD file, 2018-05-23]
hardware/desktop/nodes/hemisphere.stl
49.9 x 50.0 x 20.0

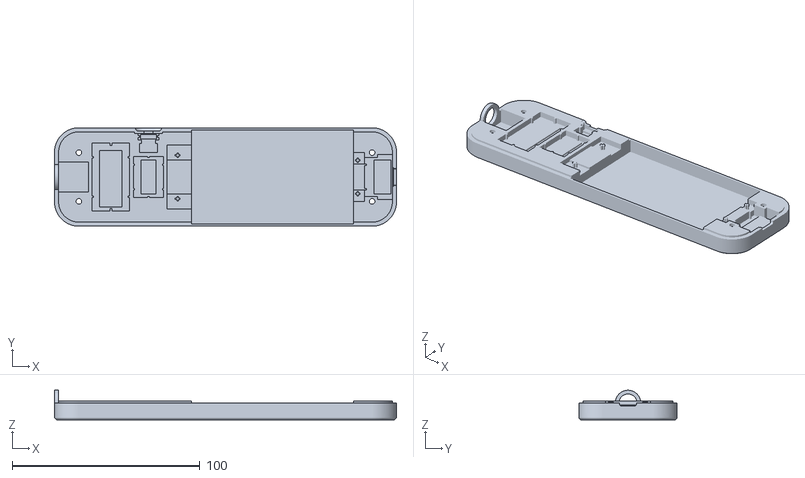
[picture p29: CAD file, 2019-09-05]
hardware/desktop/wifi_root_node/case_bottom.stl
182.0 x 52.4 x 15.8

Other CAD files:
docs/notes/117bf77c-e5ba-11e9-9ada-000c296198cf/node.3dm
hardware/desktop/nodes/hemisphere.f3d
hardware/desktop/usb_root_node/root_node.3dm
webapp/frontend/favicon.3dm
webapp/frontend/tests/vector/angle-in-x-y-plane.3dm
webapp/frontend/tests/vector/angle-to-z-axis.3dm
webapp/frontend/tests/vector/closest-point-on-centered-unit-sphere.3dm
webapp/frontend/tests/vector/closest-point-on-unit-sphere.3dm
webapp/frontend/tests/vector/int-vertical-cone-w-tetrahedral-cone-x.3dm
webapp/frontend/tests/vector/int-vertical-cone-w-tetrahedral-cone.3dm
webapp/frontend/tests/vector/rotate-to-angle-to-z-axis.3dm
webapp/frontend/tests/vector/rotate-to-tetrahedral-angle.3dm
webapp/frontend/tests/vector/tilt-angle-plus-half-tet-angle.3dm
webapp_life-size/frontend/favicon.3dm
webapp_life-size/frontend/tests/vector/angle-in-x-y-plane.3dm
webapp_life-size/frontend/tests/vector/angle-to-z-axis.3dm
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

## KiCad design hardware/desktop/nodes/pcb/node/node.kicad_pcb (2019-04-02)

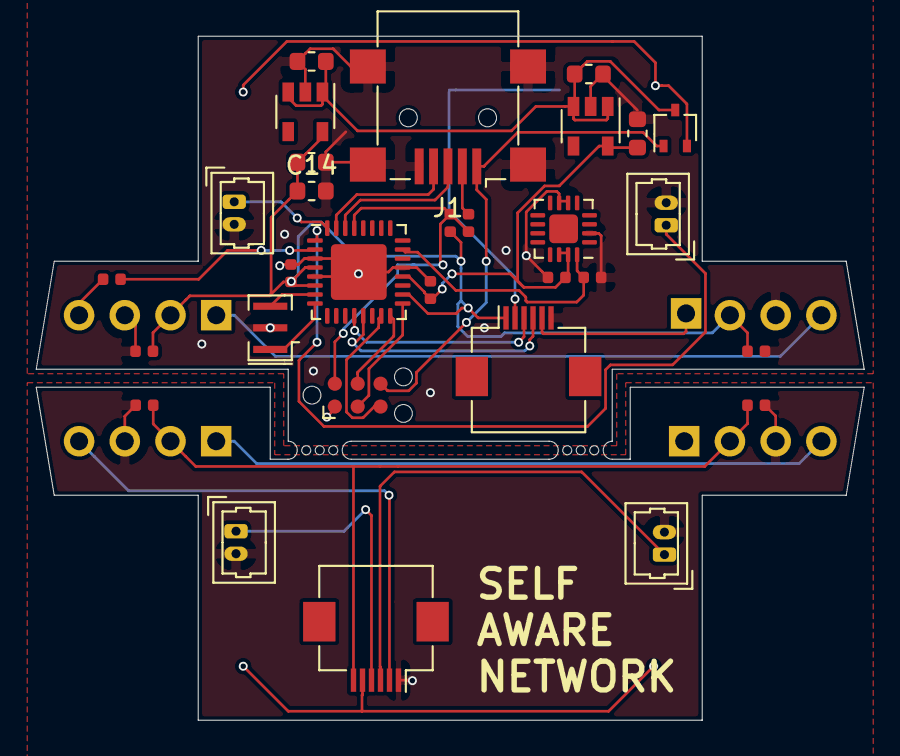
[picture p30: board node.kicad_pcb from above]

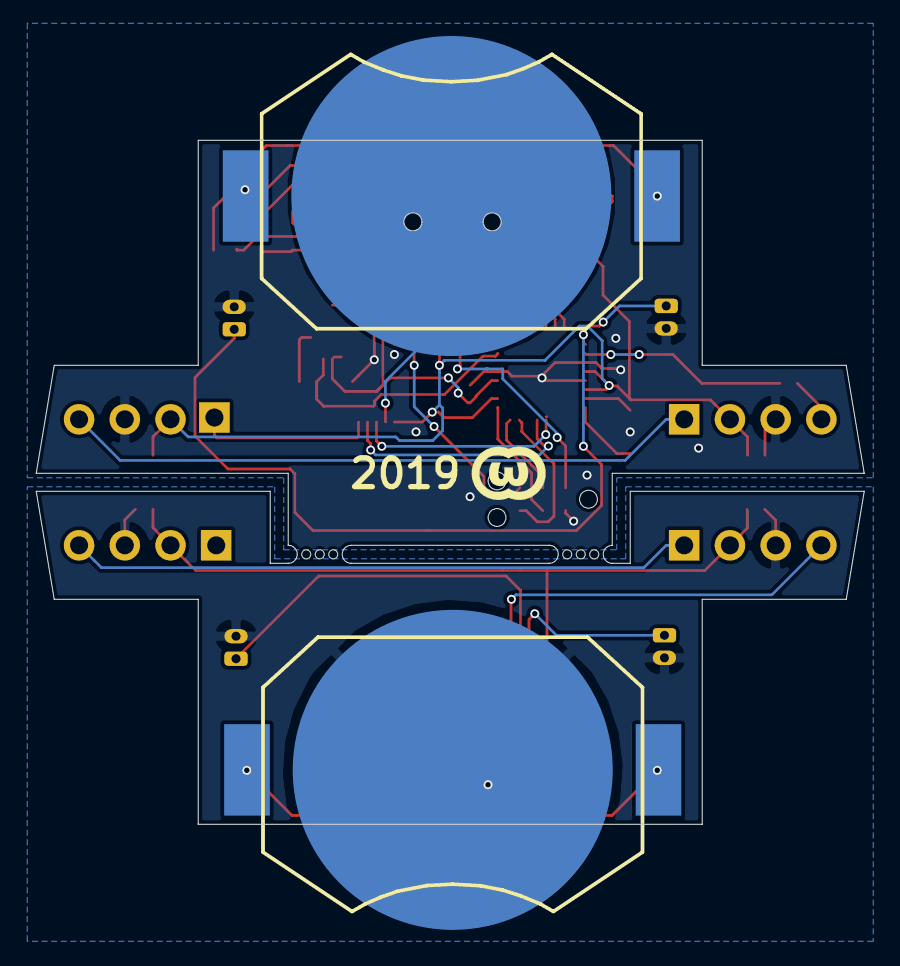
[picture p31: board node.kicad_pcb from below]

Board: 2 copper layers, 46.0 x 38.0 mm, 38 parts (2 on the bottom side), 32 nets.

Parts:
BT1, BT2: CR2032; BK-912
C1, C2, C3, C4, C14: 1u; C_0603_1608Metric
C5, C6, C7, C8, C9, C10, C11, C12, C13: 0.1u; C_0402_1005Metric
D1: BAT54CW; SOT-323_SC-70
D2, D3, D4, D5: WS2812D-F5
J1: USB_B_Mini; USB_Mini-B
J2: TC2030_NL; Tag-Connect_TC2030-IDC-NL_2x03_P1.27mm_Vertical
J3, J6: FFC-0.5MM-6POS; Hirose_FH12-6S-0.5SH_1x06-1MP_P0.50mm_Horizontal
J4: Port_1; Molex_PicoBlade_53047-0210_1x02_P1.25mm_Vertical
J5: Port_2; Molex_PicoBlade_53047-0210_1x02_P1.25mm_Vertical
J7: Port_3; Molex_PicoBlade_53047-0210_1x02_P1.25mm_Vertical
J8: Port_4; Molex_PicoBlade_53047-0210_1x02_P1.25mm_Vertical
R1: 10K; R_0402_1005Metric
R2: 470R; R_0402_1005Metric
U1: XC6204B332MR; SOT-23-5
U2: LP2985-5.0; SOT-23-5
U3: 328P-MU; QFN-32-1EP_5x5mm_P0.5mm_EP3.1x3.1mm
U4: ADXL337; LFCSP-16-1EP_3x3mm_P0.5mm_EP1.6x1.6mm
Y1: 16MHz; Resonator_SMD_muRata_CSTxExxV-3Pin_3.0x1.1mm
mouse-bite: VAL**; mouse-bite
mouse-bite#2: VAL**; mouse-bite

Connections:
+3V3: C4.1, C5.1, C8.1, U1.5, U3.20, U4.14, U4.15
+5V: C3.2, C6.1, C9.1, C11.1, C14.1, D2.2, D3.2, J3.1, R1.1, U2.5, U3.4, U3.6, U3.18
+5VB: C12.1, C13.1, D4.2, D5.2, J6.6
/Bottom hemisphere/BATT-BOT: BT2.1, J6.5
/Bottom hemisphere/BNC-3: J6.4, J7.1
/Bottom hemisphere/BNC-4: J6.3, J8.1
/Bottom hemisphere/DOUT: D4.4, J6.2
/Top Hemisphere/+5V_EXT: D1.1, J1.1, J2.6
/Top Hemisphere/BATT: BT1.1, D1.2
/Top Hemisphere/BATT-BOT: BT1.2, J3.2
/Top Hemisphere/BNC-1: J4.1, U3.32
/Top Hemisphere/BNC-2: J5.1, U3.1
/Top Hemisphere/BNC-3: J3.3, U3.12
/Top Hemisphere/BNC-4: J3.4, U3.13
/Top Hemisphere/DIN-TOP: D2.4, R2.1
/Top Hemisphere/DOUT: D3.1, J3.5
/Top Hemisphere/DTR: C7.1, J1.2
/Top Hemisphere/MISO: J2.4, U3.16
/Top Hemisphere/MOSI: J2.5, U3.15
/Top Hemisphere/RXI: J1.3, U3.30
/Top Hemisphere/SCK: J2.3, U3.17
/Top Hemisphere/TXO: J1.4, U3.31
/Top Hemisphere/VIN: C1.1, C2.1, D1.3, U1.1, U1.3, U2.1, U2.3
/Top Hemisphere/Z-ACCEL: C10.1, U3.23, U4.16
/Top Hemisphere/~RST: C7.2, J2.2, R1.2, U3.29
GND: C1.2, C2.2, C3.1, C4.2, C5.2, C6.2, C8.2, C9.2, C10.2, C11.2, C14.2, D2.3, D3.3, J1.5, J1.6, J2.1, J3.6, J4.2, J5.2, U1.2, U2.2, U3.3, U3.5, U3.21, U3.33, U4.2, U4.6, U4.7, Y1.2
GNDB: BT2.2, C12.2, C13.2, D4.3, D5.3, J6.1, J7.2, J8.2
unnamed: D2.1, D3.4
unnamed: D4.1, D5.4
unnamed: R2.2, U3.2
unnamed: U3.7, Y1.3
unnamed: U3.8, Y1.1

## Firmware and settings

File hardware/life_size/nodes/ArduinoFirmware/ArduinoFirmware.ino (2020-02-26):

// Basic algorithm idea: Parent nodes announce themselves. When a node sees the
// announcement of a parent, it creates a pair with the announcing node and
// itself and sends that via SPI.

// Pins on 328P:
//
//   * 10: SS (slave select)
//
//   * 11: MOSI (master out, slave in)
//
//   * 12: MISO (not used here)
//
//   * 13: SCK (clock)

#include "id.h" // ID of this node, e.g.: `#define ID A` (no quotes!)
#include "idUtil.h"

#include "settings.h"
#include "TransceiverOnPort.h"
#include "Port.h"
#include "Pair.h"
#include "message.h"
#include "pairMessageQueue.h"
#include "spiTransfer.h"
#include "leds.h"

static TransceiverOnPort<rxPinNumberOfPort1, txPinNumberOfPort1, 1>
  transceiverOnPort1;
static TransceiverOnPort<rxPinNumberOfPort2, txPinNumberOfPort2, 2>
  transceiverOnPort2;
static TransceiverOnPort<rxPinNumberOfPort3, txPinNumberOfPort3, 3>
  transceiverOnPort3;
static TransceiverOnPort<rxPinNumberOfPort4, txPinNumberOfPort4, 4>
  transceiverOnPort4;
static uint8_t numberOfPortWithParent = 0; // 0 = no parent, unless node ID is A
                                           // (A is always connected to root)

static uint32_t parentExpiryTime = 0; // ms

ISR(TIMER2_COMPA_vect) {
  transceiverOnPort1.transceiver.handleTimer2Interrupt();
  transceiverOnPort2.transceiver.handleTimer2Interrupt();
  transceiverOnPort3.transceiver.handleTimer2Interrupt();
  transceiverOnPort4.transceiver.handleTimer2Interrupt();
}

ISR(PCINT2_vect) { // D0-D7
  transceiverOnPort1.transceiver.handlePinChangeInterrupt();
  transceiverOnPort2.transceiver.handlePinChangeInterrupt();
}

ISR(PCINT0_vect) { // D8-D13
  transceiverOnPort3.transceiver.handlePinChangeInterrupt();
  transceiverOnPort4.transceiver.handlePinChangeInterrupt();
}

// During boot, the ESP-EYE CLK pin needs to be kept high (unless unconnected).
void waitForEspToBoot() {
  pinMode(A7, OUTPUT);
  digitalWrite(A7, LOW);
  pinMode(10, OUTPUT);
  digitalWrite(10, HIGH);
  pinMode(11, OUTPUT);
  digitalWrite(11, HIGH);
  pinMode(12, INPUT_PULLUP);
  pinMode(13, OUTPUT);
  digitalWrite(13, HIGH);
  delay(bootDelay);
}

void serialSetup() {
  Serial.begin(115200);
}

void setup() {
  waitForEspToBoot();

  spiTransferSetup();
  ledsSetup();
  serialSetup();
  multiTransceiverSetup();
}

bool iHaveAParent() {
  if (idOfThisNode == 'A') { // A is always connected to root
    return true;
  } else {
    return numberOfPortWithParent != 0;
  }
}

void parseSpiRxBuffer() {
  if (spiRxBuffer[0] != 'C') {
    return;
  }

  byte *compressedColors = spiRxBuffer + 1;
  updateLedColors(compressedColors);
}

void sendMyIdViaSpi() {
  clearSpiTxBuffer();
  spiTxBuffer[0] = 'I';
  spiTxBuffer[1] = 'D';
  spiTxBuffer[2] = '=';
  spiTxBuffer[3] = idOfThisNode;
  doSpiTransfer();
  parseSpiRxBuffer();
}

void periodicallySendMyIdViaSpi() {
  static uint32_t scheduledSendTime = millis() + idSendPeriod; // ms
  uint32_t now = millis(); // ms

  if (now >= scheduledSendTime) {
    sendMyIdViaSpi();
    scheduledSendTime = now + idSendPeriod;
  }
}

void parseMessages() {
  bool messageHasBeenReceived;

  do {
    messageHasBeenReceived = false;
    messageHasBeenReceived |= 
      parseMessage(transceiverOnPort1, transceiverOnPort1.getMessage());
    messageHasBeenReceived |=
      parseMessage(transceiverOnPort2, transceiverOnPort2.getMessage());
    messageHasBeenReceived |=
      parseMessage(transceiverOnPort3, transceiverOnPort3.getMessage());
    messageHasBeenReceived |=
      parseMessage(transceiverOnPort4, transceiverOnPort4.getMessage());
  } while (messageHasBeenReceived);
}

void sendPairViaSpi(const Pair &pair) {
  clearSpiTxBuffer();
  spiTxBuffer[0] = pair.parentPort.nodeId;
  spiTxBuffer[1] = charFromDigit(pair.parentPort.portNumber);
  spiTxBuffer[2] = pair.childPort.nodeId;
  spiTxBuffer[3] = charFromDigit(pair.childPort.portNumber);
  doSpiTransfer();
  parseSpiRxBuffer();
}

void loop() {
  periodicallySendMyIdViaSpi();
  parseMessages();
  periodicallyAnnounceMe();
  removeParentIfExpired();
}

bool transmissionToParentIsInProgress() {
  if (numberOfPortWithParent == transceiverOnPort1.portNumber) {
    return transceiverOnPort1.transceiver.transmissionIsInProgress();
  }
  if (numberOfPortWithParent == transceiverOnPort2.portNumber) {
    return transceiverOnPort2.transceiver.transmissionIsInProgress();
  }
  if (numberOfPortWithParent == transceiverOnPort3.portNumber) {
    return transceiverOnPort3.transceiver.transmissionIsInProgress();
  }
  if (numberOfPortWithParent == transceiverOnPort4.portNumber) {
    return transceiverOnPort4.transceiver.transmissionIsInProgress();
  }
  return false;
}

void removeParent() {
  numberOfPortWithParent = 0;
}

void removeParentIfExpired() {
  if (iHaveAParent() && millis() > parentExpiryTime) {
    removeParent();
  }
}

void periodicallyAnnounceMe() {
  static uint32_t scheduledAnnouncementTime =
    millis() + announcementPeriod; // ms
  uint32_t now = millis(); // ms

  if (now >= scheduledAnnouncementTime) {
    announceMeToChildren();
    scheduledAnnouncementTime = now + announcementPeriod;
  }
}

static inline uint8_t digitFromChar(char c) {
  return c - 48;
}

static inline char charFromDigit(uint8_t digit) {
  return digit + 48;
}

template <typename T>
void sendPairMessageToParent(T &transceiverOnPort, const byte *pairMessage) {
  transceiverOnPort.transceiver.startTransmissionOfBytes(pairMessage,
                                                         pairMessageSize);
}

void enablePinChangeInterrupts() {
  PCICR |= // Pin Change Interrupt Control Register
    bit(PCIE2) | // D0 to D7
    bit(PCIE0); // D8 to D15
}

void multiTransceiverSetup() {
  multiTransceiver.startTimer1();
  multiTransceiver.startTimer2();
  enablePinChangeInterrupts();
  transceiverOnPort1.transceiver.begin();
  transceiverOnPort2.transceiver.begin();
  transceiverOnPort3.transceiver.begin();
  transceiverOnPort4.transceiver.begin();
}

template <typename T>
void transmitAnnouncement(T &transceiverOnPort) {
  transceiverOnPort.transceiver.startTransmissionOfBytes(
    buildAnnouncementMessage({idOfThisNode, transceiverOnPort.portNumber}),
    announcementMessageSize
  );
}

template <typename T>
void announceMeToChild(T &transceiverOnPort) {
  if (transceiverOnPort.portNumber == numberOfPortWithParent) {
    return;
  }
  transmitAnnouncement(transceiverOnPort);
}

void resetParentExpiryTime() {
  parentExpiryTime = millis() + parentExpiryDuration; // ms
}

template <typename T>
void parseAnnouncementMessage(T &transceiverOnPort, const byte *message) {
  if (thisNodeIsRoot()) {
    return; // root cannot have a parent => ignore announcement
  }

  if (!iHaveAParent()) {
    numberOfPortWithParent = transceiverOnPort.portNumber;
  }

  if (transceiverOnPort.portNumber == numberOfPortWithParent) {
    resetParentExpiryTime(); // call regularly to keep parent fresh
  }

  // Create pair, either describing a parent-child relationship or a loop:
  Port port = decodePort(message[1]);
  Pair pair;
  pair.parentPort = port;
  pair.childPort = {idOfThisNode, transceiverOnPort.portNumber};

  sendPairViaSpi(pair);
}

static inline Pair pairFromPairMessage(const byte *message) {
  Pair pair;
  pair.parentPort = decodePort(message[1]);
  pair.childPort = decodePort(message[2]);
  return pair;
}

template <typename T>
bool parseMessage(T &transceiverOnPort, byte *message) {
  if (message == 0) {
    return false;
  }

  if (message[0] & B01000000) {
    // pair message, ignore (not needed in this version)
    return true;
  } else {
    // announcement message
    parseAnnouncementMessage(transceiverOnPort, message);
    return true;
  }
  return false;
}

void sendPairMessageToParent(const byte *pairMessage) {
  if (numberOfPortWithParent == transceiverOnPort1.portNumber) {
    sendPairMessageToParent(transceiverOnPort1, pairMessage);
  } else if (numberOfPortWithParent == transceiverOnPort2.portNumber) {
    sendPairMessageToParent(transceiverOnPort2, pairMessage);
  } else if (numberOfPortWithParent == transceiverOnPort3.portNumber) {
    sendPairMessageToParent(transceiverOnPort3, pairMessage);
  } else if (numberOfPortWithParent == transceiverOnPort4.portNumber) {
    sendPairMessageToParent(transceiverOnPort4, pairMessage);
  }
}

void announceMeToChildren() {
  announceMeToChild(transceiverOnPort1);
  if (!thisNodeIsRoot()) {
    announceMeToChild(transceiverOnPort2);
    announceMeToChild(transceiverOnPort3);
    announceMeToChild(transceiverOnPort4);
  }
}

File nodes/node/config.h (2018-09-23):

#ifndef config_h
#define config_h

#include "Arduino.h"

#undef DEBUG

const uint8_t ledPin = 13;
const uint8_t pairBufferSize = 4; // TODO: increase

#ifdef DEBUG
const boolean flashLedIsEnabled = true; // takes time
const uint32_t announcementPeriod = 2000; // ms
const uint8_t bitDurationExp = 9;
#else
const boolean flashLedIsEnabled = false;

// The maximum data rate supported by MultiTrans when communicating
// with four neighboring nodes is at about ~3kbit/s uni-directionally
// (bit duration exponent: 11).
// 
// On stability problems, reduce the data rate (by increasing the bit
// duration exponent) and increase the announcement period.
const uint8_t bitDurationExp = 11;

// The announcement period needs to be long enough so that all pairs
// can be transmitted in between two announcements. It depends on the
// bit rate as well as on the maximum number of nodes.
//
// For now, it can be estimated experimentally by connecting all nodes
// in a row and looking at the output. One needs to keep in mind,
// though, that loops can increase the number of pairs
// considerably. So maybe it's best to multiply the result with a
// factor. In the end it may be possible to calculate the annoncement
// period automatically.
const uint32_t announcementPeriod = 150; // ms // TODO: take from common settings
#endif

#endif

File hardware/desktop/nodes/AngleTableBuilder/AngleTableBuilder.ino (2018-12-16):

const uint8_t accelerometerPin = A0;

uint16_t minReadout, maxReadout;
const unsigned long printInterval = 500; // ms

void setup() {
  analogReference(EXTERNAL);
  Serial.begin(9600);
  reset();
}

float acceleration(const uint16_t readout) { // g
  // Based on experimentation, trimming mitigates issues with singularities and
  // low angular resolution at the poles:
  float trimValue = 1;
  float trimmedMinReadout = minReadout + trimValue;
  float trimmedMaxReadout = maxReadout - trimValue;

  float readoutPerG = float(trimmedMaxReadout - trimmedMinReadout) / 2;
  float zeroGReadout = trimmedMinReadout + readoutPerG;
  return (float(readout) - zeroGReadout) / readoutPerG;
}

// Tilt angle measured against the z axis pointing upwards. With the node's
// top sphere up, the tilt angle should be zero.
float angle(uint16_t readout) { // deg
  float acc = acceleration(readout);
  float clippedAcc = min(1, max(-1, acc)); // [-1, 1]
  return acos(-clippedAcc) * 360 / 2 / PI;
}

// [0, 180] -> [1, 127] (0 excluded, because that means: no angle)
uint16_t encodedAngle(uint16_t readout) {
  float a = angle(readout);
  return round(a * 126 / 180) % 127 + 1;
}

void printAngleTable() {
  uint16_t readout = 0;
  for (uint8_t row = 0; row < 128; row ++) {
    for (uint8_t column = 0; column < 8; column ++) {
      Serial.print("0x");
      Serial.print(encodedAngle(readout), HEX);
      Serial.print(readout < 1023 ? "," : "");
      Serial.print(column < 7 ? " " : "");
      readout ++;
    }
    Serial.println();
  }
}

void printStatus(uint16_t lastReadout) {
  char s[5];
  Serial.print("last readout = ");
  sprintf(s, "%4d", lastReadout);
  Serial.print(s);
  Serial.print(", min. readout = ");
  sprintf(s, "%4d", minReadout);
  Serial.print(s);
  Serial.print(", max. readout = ");
  sprintf(s, "%4d", maxReadout);
  Serial.print(s);
  Serial.println(" (send: `t` to print table, `r` to reset)");
}

uint16_t measure() {
  uint16_t readout = analogRead(accelerometerPin);
  minReadout = min(readout, minReadout);
  maxReadout = max(readout, maxReadout);
  return readout;
}

void reset() {
  minReadout = 0xffff;
  maxReadout = 0;
}

void iterate() {
  static unsigned long scheduledPrintTime = millis();
  uint16_t readout = measure();
  unsigned long currentTime = millis();
  if (currentTime >= scheduledPrintTime) {
    printStatus(readout);
    scheduledPrintTime = currentTime + printInterval;
  }
}

void loop() {
  static bool finished = false;

  while (Serial.available() > 0) {
    char c = Serial.read();
    switch (c) {
    case 't':
      printAngleTable();
      finished = true;
      break;
    case 'r':
      reset();
      finished = false;
      break;
    }
  }

  if (!finished) {
    iterate();
  }
}

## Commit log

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2018-02-11 Fix: Messages with invalid elements
    [Port.h]
2018-02-14 Attempt to add check for loop (doesn't work yet)
    [Port.h, config.h]
2018-02-16 Fix: Reading does not wait till end of cycle
    [Port.h]
2018-02-17 Add documentation about idea for power
    [draft.3dm, mesh.3dm, sequence.3dm]
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2018-03-15 Add instructions for connector; Add illustration
    [simple_sequence.3dm]
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2018-04-02 Add function to rotate unit vector in place
    [test-coordinates.3dm]
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2018-04-11 Move favicon source out of public
    [favicon.3dm]
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2018-05-23 Improve documentation for assembly
    [draft.3dm, hemisphere.f3d, hemisphere.stl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]
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2018-09-01 Fix bugs with chaining; Introduce expiry time
    [Port.h]
2018-09-04 Add info for debugging transmission errors
    [Port.h, config.h]
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2018-09-20 Add optional bottom hemisphere
    [hemisphere.f3d, hemisphere_optional_bottom.stl]
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2018-09-25 Fix: Lines randomly disappear when moving camera
2018-09-26 Remove outdated comment
    Comment doesn't apply to Arduino Pro Mini.
    [Firmware.ino]
2018-09-29 Correct name for include guard
    [Firmware.ino]
2018-10-03 Chamfer screw holes
    Fixes issue with collapsing overhangs on print.
    [root_node.3dm]
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2018-10-17 Fix case
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2018-11-22 Fix: lines too long
    [Firmware.ino]
2018-11-22 Fix: max. no. bytes / transmis. larger than needed
    [TransceiverOnPort.h]
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2018-12-03 Add function to add tilt and tetrahedral angles
    [tilt-angle-plus-half-tet-angle.3dm]
2018-12-05 Add another test, illustrate ranges
    [tilt-angle-plus-half-tet-angle.3dm]
2018-12-05 Add functions for positioning points
    [closest-point-in-range-on-sphere.3dm, rotate-to-angle-to-z-axis.3dm, tilt-angle-plus-half-tet-angle.3dm]
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2018-12-10 Finish first set of tests
    [closest-point-in-range-on-sphere.3dm, rotate-to-angle-to-z-axis.3dm]
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2018-12-11 Add second set of tests
    [closest-point-on-unit-sphere.3dm]
2018-12-11 Add third set of tests
    [closest-point-on-unit-sphere.3dm]
2018-12-11 Rename to prepare for center option
    [closest-point-on-unit-sphere.3dm]
2018-12-11 Add test implementations and illustrations
    [closest-point-on-unit-sphere.3dm]
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2018-12-13 Add tests for angle range of size 0
    [closest-point-on-centered-unit-sphere.3dm]
2018-12-13 Implement and test case of invalid range
    [closest-point-on-centered-unit-sphere.3dm]
2018-12-13 Add measurement of angle in xy plane
    [angle-in-x-y-plane.3dm]
2018-12-14 Implement basic cone intersection
    [int-vertical-cone-w-tetrahedral-cone-x.3dm]
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2018-12-14 Make axis at tetrahedral angle basically work
    [tilt-angle-plus-half-tet-angle.3dm]
2018-12-15 Move to polar coordinates
    [int-vertical-cone-w-tetrahedral-cone-x.3dm]
2018-12-15 Implement basic fall back in case of close touch
    [int-vertical-cone-w-tetrahedral-cone-x.3dm]
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2018-12-15 Replace useless tests with important tests
    [int-vertical-cone-w-tetrahedral-cone-x.3dm]
2018-12-15 Add tests for intVerticalConeWTetrahedralCone
    [int-vertical-cone-w-tetrahedral-cone.3dm]
2018-12-16 Fix: Tilt angle upside down
    [AngleTableBuilder.ino]
2018-12-18 Fix: angle range too big
    [tilt-angle-plus-half-tet-angle.3dm]
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2018-12-18 Move center in test
    [closest-point-on-unit-sphere.3dm]
2018-12-18 Fix: rounding errors not handled well
    [closest-point-on-centered-unit-sphere.3dm]
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2018-12-18 Fix: excluded angle not handled correctly
    [tilt-angle-plus-half-tet-angle.3dm]
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2019-01-09 Add examples with data
    [1-1-adjacency.tsv, 1-1-coordinates.tsv, hexagon-adjacency.tsv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]
2019-01-10 Add missing images and data
    [dodecahedron-adjacency.tsv]
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2019-03-13 Add PCB layout (WIP)
    [neopixel.sch, node.kicad_pcb, node.sch]
2019-03-13 Fix ERC errors (except for 2 which can be ignored)
    [neopixel.sch, node.sch]
2019-03-15 Add document about PCB dimensions
    [32A.step, 533980271.stp, APFA3010.STEP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]
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2019-03-19 Start simplified Seeed OPL compatible circuit
    [neopixel.sch, node.kicad_pcb, node.sch]
2019-03-20 Refactored schematic, placed components, no wiring
    [_saved_top.sch, bottom.sch, top-hemi.csv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]
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2019-03-20 Fix: wrong ignore file for KiCad projects
2019-03-20 Move BNC connectors to correct hemispheres
    Positions within the hemisphere don’t matter.
    [_saved_top-hemi.sch, _saved_top.sch, bottom.sch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]
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2019-03-21 Corrected route not connected
    [top-hemi.kicad_pcb]
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2019-03-21 Plotted gerber and drill for Seeed
    [top-hemi-B_Cu.gbl, top-hemi-B_Mask.gbs, top-hemi-B_Paste.gbp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]
2019-03-21 Redid GND pour on bottom hemisphere
    [top-hemi-B_Cu.gbl, top-hemi-B_Mask.gbs, top-hemi-B_Paste.gbp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]
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2019-03-22 Change PCB thickness to 1mm (for 3D view)
    [top-hemi.kicad_pcb]
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2019-03-22 Route some more at the top
    [top-hemi.kicad_pcb]
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2019-03-22 Match sheets in size
    [top-hemi.sch]
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2019-03-22 Reduce pour clearance to 10mils (>= 8mils specs)
    Seeed specs:
    http://support.seeedstudio.com/knowledgebase/articles/447362-fusion-pcb-specification
    [top-hemi.kicad_pcb]
2019-03-22 Finish routing top board
    [top-hemi.kicad_pcb]
2019-03-22 Fix airwires, tighten GND zones (within specs)
    [top-hemi.kicad_pcb]
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2019-03-22 Swap LEDs 3 and 4
    [top-hemi.kicad_pcb]
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2019-03-23 Connect USB-Mini shield to GND
    [bottom.sch, top-hemi.kicad_pcb, top.sch]
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2019-03-23 Choose more descriptive name
    [bottom.sch, node.kicad_pcb, node.sch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]
2019-03-23 Add text on silkscreen
    [node.kicad_pcb]
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2019-03-24 Switch to small mouse-bite
    [node.kicad_pcb]
2019-03-24 Fix: critically small features in license logo
    [node.kicad_pcb]
2019-03-24 Annotate GND for ports
    [node.kicad_pcb]
2019-03-24 Make designators invisible on silkscreen
    [node.kicad_pcb]
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2019-03-24 Replace 2x1 header footprint by port footprint
    [bottom.sch, node.kicad_pcb, top.sch]
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2019-03-24 Switch to WS2812D-F5 footprints
    [bottom.sch, node.kicad_pcb, top.sch]
2019-03-24 Remove via in the middle to PTH
    [node.kicad_pcb]
2019-03-24 Fix DRC errors
    [node.kicad_pcb]
2019-03-24 Use ADXL335 from globally installed SparkFun lib
    [top.sch]
2019-03-24 Fix: ADXL335 footprint too small (3x3 vs. 4x4)
    [top.sch]
2019-03-24 Fix: footprint assignment not applied
    [top.sch]
2019-03-24 Switch to ADXL337: smaller & same pitch as 328P-MU
    [top.sch]
2019-03-24 Assign footprint to ADXL337
    [top.sch]
2019-03-24 Connect ST to GND, to be on the safe side
    [top.sch]
2019-03-24 Revice voltage regulator circuits
    [top.sch]
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2019-03-24 Swap pins on LED (other pinout as NeoPixel_THT)
2019-03-24 Switch to WS2812D-F5 (NeoPixel w/ diff. pinout)
    [bottom.sch, top.sch]
2019-03-24 Give more space to LEDs in enclosure (new outline)
    [node.kicad_pcb]
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2019-03-25 Move components and extend board (less fragile)
    [node.kicad_pcb]
2019-03-25 Switch to separate power symbols for bottom
    Then DRC doesn’t need to know how bottom and top power nets are
    connected.
    [bottom.sch, node.kicad_pcb]
2019-03-25 Create separate GND pours for top and bottom
    [node.kicad_pcb]
2019-03-25 Fix: missing king in top GND pour on bottom board
    [node.kicad_pcb]
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2019-03-25 Configure ADXL337 pins to avoid ERC warnings
    [top.sch]
2019-03-25 Rename nets, fix ERC warnings and errors
    [bottom.sch, node.sch, top.sch]
2019-03-25 Correct pin types in 5V LDO symbol
    [top.sch]
2019-03-25 Set footprint for ADXL337
    [top.sch]
2019-03-25 Set footprint for 5V LDO
    [top.sch]
2019-03-25 Reload footprints (without change)
    [node.kicad_pcb]
2019-03-25 Hide references of new footprints
    [node.kicad_pcb]
2019-03-25 Fix: bottom FFC connector has wrong pinout
    [bottom.sch, node.kicad_pcb]
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2019-03-25 Update entries for Seeed BOM
    [bottom.sch, top.sch]
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2019-03-26 Reround for better connection b/w GND and caps
    [node.kicad_pcb]
2019-03-27 Reroute for better connection b/w GND and caps
    [node-B_Cu.gbl, node-B_Mask.gbs, node-B_Paste.gbp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]
2019-03-27 Fix: PCB design in wrong directory
    [bottom.sch, node.kicad_pcb, node.sch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]
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2019-03-28 Fix: LEDs offset
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2019-04-02 Add data for assembly drawing file (on F.Fab)
    [node.kicad_pcb]
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2019-04-11 Point to issue with collision resistor and LED leg
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2019-06-06 Fix: Graph doesn’t show in Firefox
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2019-06-10 Make node links work and fix connector positions
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2019-06-11 Fix: Border missing for selected radio buttons
2019-06-11 Fix: Radio buttons slightly shifted in flex
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2019-06-16 Filter noise
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2019-06-20 Attempt to normalize white noise (doesn’t work)
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2019-07-23 Fix: Web socket data not sent
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2019-10-20 Fix quirks
    [node.3dm]
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2019-11-14 Make directory name more generic, not only ESP-EYE
    [partitions.csv]
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2019-11-21 Reset SPI pins back to ESP-EYE pinout
    [app_spi.c]
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2019-11-28 Fix: Pair not sent by SPI
    [ArduinoFirmware.ino]
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2020-01-07 Use newer serial module (old one doesn’t compile)
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2020-01-13 Fix: serial port list doesn’t work
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2020-02-17 Remove color command: doesn’t belong in simulate
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2020-02-24 Don’t continue on error
2020-02-25 Dial back brightness (drains batteries too fast)
    [settings.h]
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2020-02-26 Fix: doesn’t compile
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
